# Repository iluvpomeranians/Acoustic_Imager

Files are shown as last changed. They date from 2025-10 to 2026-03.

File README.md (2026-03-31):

# Acoustic Imager – Real-Time Sound Localization

## Overview

This repository contains an **acoustic imaging system** (COEN 490 capstone). A **16-microphone array** localizes sound sources and displays real-time heatmaps, with optional camera overlay, bandpass filtering, and multiple data sources (hardware SPI, simulated, loopback, reference).

https://github.com/user-attachments/assets/3cb0d738-56af-4772-b79c-725c6c1b056e

---

## Key Features

- **16-mic array**: Fermat spiral layout for simulation; measured geometry for hardware (HW/LOOP)
- **Real-time beamforming**: MUSIC and ESPRIT, with 2D MUSIC and covariance smoothing for HW
- **Data sources**: HW (SPI), SIM (simulated), LOOP (SPI loopback), REF (0 dB baseline)
- **Interactive heatmap**: Camera overlay, bandpass filter (draggable range), dB colorbar, colormap options (MAGMA, JET, TURBO, INFERNO)
- **Crosshairs**: Tap heatmap for crosshair with level/trend tooltip; optional 3 s / 12 s tracking
- **Spectrum analyzer**: Frequency bar with cursor; dB / NORM / dBA modes
- **UI**: Frame rate (30 / 60 / MAX), gain (LOW/HIGH), Wi‑Fi modal, settings modal, gallery, video recording, screenshots
- **Position & radar**: Optional compass (magnetometer), GPS, Wi‑Fi geolocation, radar map widget, directional history logging
- **Calibration**: Calibration suite (in-app), camera–array alignment constants, per-mic gain and HW geometry in config

---

## Project Objectives

- Achieve **~9° angular resolution** with a 16-mic array
- Manage spatial aliasing above ~8.6 kHz using **subspace methods** (MUSIC/ESPRIT)
- **Low-level acquisition** on STM32 with SPI transfer to Raspberry Pi
- **Real-time visualization** with interactive controls and multiple sources
- Deliver a **maintainable prototype** with modular software

---

## Team

- **David** – DSP lead, MUSIC/ESPRIT, visualization
- **Basem** – C++ DSP, software architecture
- **Fabian** – Requirements, integration testing
- **Tim** – Literature review, peripheral testing
- **Rob** – Hardware selection, PCB design
- **Ahmad** – Housing, assembly, CAD

---

## Quick Start

Run the application using the deploy script from the repository root:

```bash
sudo ./deploy/deploy_imager.sh
```

First run installs system packages (Python, OpenCV, libcamera, etc.), sets up the systemd service, and starts the UI. On later runs the script only toggles DEV mode or service state unless you request a clean reinstall.

**Clean reinstall** (remove existing service and reinstall):

```bash
sudo ./deploy/deploy_imager.sh --clean
```

Other options: `-status` to show service status, `-dev` to enable/disable DEV mode (skip auto-start for development).

---

## Calibration & Array Geometry

### Array geometry

- **Simulation (SIM)**: Fermat spiral in `config.py` — golden angle ~137.5°, aperture radius 1 cm, `x_coords` / `y_coords` in meters.
- **Hardware (HW / LOOP)**: Measured positions in **payload order** (0=U3 … 15=U14) as `x_coords_hw` and `y_coords_hw` in `config.py`. Generated from `utilities/calibration/array_geometry/`; see `array_geometry.md` for table, CSV, and MUSIC input reference.
- **Pitch**: Mean radial spacing (e.g. `pitch_hw` for HW) is used by the pipeline; geometry scripts output it for reference.

### Camera–array calibration

- In `config.py`: `CALIBRATION_DISTANCE_INCHES` (camera to array center), `CALIBRATION_OFFSET_INCHES` (lateral offset; positive = array right of camera center). Used for overlay alignment and tests. See `utilities/calibration/calibration_test.md` for the test setup.

### Per-mic and pipeline tuning

- **Per-mic gain**: `SPI_MIC_GAIN` in `config.py` (length 16); use `utilities/calibration/metrics_debug.py --live --write-config` to tune.
- **Calibration suite**: In-app via **Settings → Calibration Suite**; can run calibration flow and export results. Standalone app: `utilities/calibration/calibration_standalone_app.py`.

---

## User Interface & Controls

### Mouse

- **Left click**: Buttons, menu items, pills, bandpass handles (drag to set frequency range on the frequency bar).
- **Heatmap**: Tap to show crosshair and level/trend tooltip; tap again near crosshair to dismiss.
- **Spectrum bar**: Double-tap toggles cursor; single tap places or moves the dot.
- **Swipe down** (from top or bottom): Hide top HUD or bottom HUD + menu.
- **Swipe up**: Show HUD/menu. When menu is open, one swipe down closes menu; second swipe hides bottom HUD.
- **Swipe left**: Show menu (horizontal).
- **Single tap** in content (with menu open): Close menu.

### Keyboard

- **Q** or **ESC**: Quit.

### Bottom bar (pills)

- **SHOT**: Screenshot (saved to output folder; gallery refreshes).
- **REC**: Start recording; when recording, same pill toggles **PAUSE**; when paused, **Resume** (yellow) and **Stop** (red) appear.
- **Gallery**: Open gallery (grid of captures/videos; swipe/scroll, select, delete, tags, archive folders).

### Menu (dropdown)

- **Menu** button opens dropdown:
  - **Wi‑Fi**: Scan, connect, disconnect; password screen and on-screen keyboard.
  - **Settings**: Camera on/off, crosshairs, colormap, debug overlay, radar UI, map style (dark/light), position services, record compass history, **Calibration Suite**, email settings, flash firmware. Scrollable panel.
  - **30FPS / MAX**: Frame rate limit (30 or MAX; 60 removed in current UI).
  - **GAIN**: Toggle LOW / HIGH (drives hardware when gain control enabled).
  - **SRC**: Cycle source — HW → SIM → LOOP → REF.
  - **SPECTRUM**: Cycle spectrum mode — dB → NORM → dBA.

### Other UI

- **Top HUD**: Time, battery, FPS, network (e.g. SPI rate); tap pills to expand details.
- **Debug overlay**: Frame count, FPS, source stats, throughput (when debug enabled in settings).
- **Radar widget**: Optional mini map with heading and detections (when radar UI and position services enabled).

---

## Performance

- **FPS modes**: 30, 60 (if re-enabled), or MAX (no cap). Throttling applied each frame when not MAX.
- **Typical (Raspberry Pi 4)**: SIM can reach 60 FPS; HW/LOOP depends on SPI rate and MUSIC/heatmap cost (often 30–60 FPS). Camera overlay and 2D MUSIC reduce FPS.
- **Profiler**: Every 60 frames the main loop prints average stage timings (e.g. `read_source`, `heat_music`, `heat_draw`, `background`, `blend`, `bars`, `ui`, `imshow`, `waitKey`, `total` in ms). Use to find bottlenecks.
- **Tips**: Use 30 FPS when full rate isn’t needed; disable camera or radar if not used; tune `SPI_MUSIC_EVERY_N_FRAMES` and 2D coarse/fine resolution in `config.py` to trade smoothness for speed.

---

**Last updated**: March 2026

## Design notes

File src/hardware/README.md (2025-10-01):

# Hardware

This folder contains all schematics, PCB designs, and CAD files for the device.

---

### Component Testing
- **HF-02-01: Microphone IC Testing**  
  Verify MEMS mic sensitivity and noise floor.  

- **HF-02-02: STM32H7 Testing**  
  Confirm development board boots, runs firmware, and handles acquisition.  

- **HF-02-03: LCD Touchscreen Testing**  
  Ensure the 7-inch display responds to touch and renders frames correctly.  

---

### Power
- **HF-03-01: Battery Pack Assembly**  
  Assemble 18650 battery pack with BMS.  

- **HF-03-02: Power Management**  
  Add regulation circuits for stable 5V/3.3V rails.  

- **HF-03-03/04: Electrical Budget Estimation**  
  Estimate current draw for STM32 and Raspberry Pi subsystems.  

- **HF-03-05: Power Testing**  
  Verify ≥2 hrs runtime and measure voltage sag.  

---

### Mechanical Housing
- **HF-04-01: CAD Design**  
  Design enclosure for mic array, Pi, STM32, battery, and display.  

---

### PCB Design & Testing
- **HF-05-01: Microphone Array Schematic**  
  Draft schematic for mic array connections and decoupling.  

- **HF-05-03/04: Embedded/Power Schematic & Layout**  
  Draw schematic and PCB for STM32, regulators, and connectors.

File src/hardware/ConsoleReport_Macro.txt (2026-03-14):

# ImagerTracker.FCMacro
# Finite, readable “tracker” for Report View: placements + BBoxes + volume/area + Body feature lists
# Also prints a small DELTA vs last run (so you see what changed) without spamming.

import FreeCAD as App
import math, time, json

doc = App.ActiveDocument
if not doc:
    raise RuntimeError("No ActiveDocument. Open your .FCStd first.")

# =======================
# SETTINGS (edit these)
# =======================
MODE = "INCLUDE"          # "INCLUDE" or "SELECTION"
INCLUDE = [
    "Front","Back","Pi5","PowerBoard","Audio_Simpler_PCB","Auidio_Simpler_PCB",
    "rpi_camera_g_detailed","rpi_camera_g_detailed_body_only001","rpi_camera_g_detailed_body_only",
    "rpi_camera_g_detailed_body_only001","rpi_camera_g_detailed_body_only001",
    "LCD","Fan40","BatteryPack_Envelope","BatteryCells_2S2P",
    # common “reference container” names you might be using:
    "References",
]
REF_NAME = ""             # optional: e.g. "Front" ("" disables relative output)

SHOW_SHAPE_STATS = True   # volume/area if available
SHOW_BODY_TREE  = True    # list PartDesign features in each body
MAX_OBJECTS = 80
MAX_FEATURES_PER_BODY = 60
MAX_SKETCH_INFO = 20      # print sketch info for up to N sketches total
PRINT_SKETCH_SUMMARY = True

BB_LIMIT = 1e6

# =======================
# Helpers
# =======================
def bb_is_insane(bb, limit=BB_LIMIT):
    m = max(abs(bb.XMin), abs(bb.XMax), abs(bb.YMin), abs(bb.YMax), abs(bb.ZMin), abs(bb.ZMax))
    return m > limit

def get_obj(key):
    o = doc.getObject(key)
    if o: return o
    try:
        hits = doc.getObjectsByLabel(key)
        if hits: return hits[0]
    except:
        pass
    return None

def safe_shape(o):
    try:
        sh = o.Shape
        if sh.isNull():
            return None
        bb = sh.BoundBox
        if bb_is_insane(bb):
            return None
        return sh
    except:
        return None

def placement_of(o):
    try:
        if hasattr(o, "getGlobalPlacement"):
            return o.getGlobalPlacement()
    except:
        pass
    return o.Placement

def rot_pack(r):
    ax = r.Axis
    ang = math.degrees(r.Angle)
    try:
        q = tuple(r.Q)  # (x,y,z,w)
    except:
        q = None
    return ax, ang, q

def rel_placement(pl_ref, pl_obj):
    try:
        return pl_ref.inverse().multiply(pl_obj)
    except:
        rp = App.Placement()
        rp.Base = pl_obj.Base.sub(pl_ref.Base)
        rp.Rotation = pl_obj.Rotation
        return rp

def fmt_vec(v):
    return f"({v.x:.3f}, {v.y:.3f}, {v.z:.3f})"

def fmt_bb(bb):
    return f"X[{bb.XMin:.2f},{bb.XMax:.2f}] Y[{bb.YMin:.2f},{bb.YMax:.2f}] Z[{bb.ZMin:.2f},{bb.ZMax:.2f}]"

def fmt_size(bb):
    return f"W={bb.XLength:.2f}  T={bb.YLength:.2f}  H={bb.ZLength:.2f}"

# =======================
# Delta store (so you can see changes run-to-run)
# =======================
PARAM_PATH = "User parameter:BaseApp/Preferences/Macros/ImagerTracker"
pg = App.ParamGet(PARAM_PATH)

def load_prev():
    try:
        s = pg.GetString("prev_state", "")
        if not s:
            return {}
        return json.loads(s)
    except:
        return {}

def save_prev(state):
    try:
        pg.SetString("prev_state", json.dumps(state))
    except:
        pass

prev_state = load_prev()
cur_state = {}

# =======================
# Select targets
# =======================
targets = []

if MODE.upper() == "SELECTION":
    # If you want selection mode, select objects in tree, then run macro
    sel = App.Gui.Selection.getSelection() if App.GuiUp else []
    targets = sel[:MAX_OBJECTS]
else:
    # INCLUDE mode: match by Name OR Label
    for o in doc.Objects:
        if len(targets) >= MAX_OBJECTS:
            break
        if INCLUDE:
            if (o.Name not in INCLUDE) and ((getattr(o, "Label", "") or "") not in INCLUDE):
                continue
        targets.append(o)

# reference object (optional)
ref = get_obj(REF_NAME) if REF_NAME else None
ref_pl = placement_of(ref) if ref else None

# =======================
# Print header
# =======================
print("\n=== ImagerTracker (finite) ===")
print("Time:", time.strftime("%Y-%m-%d %H:%M:%S"))
print("Doc :", doc.Name)
try:
    print("File:", doc.FileName)
except:
    pass

if MODE.upper() == "SELECTION":
    print("Mode: SELECTION")
else:
    print("Mode: INCLUDE  (edit INCLUDE list at top)")

if ref:
    print(f"Reference: {ref.Name} ({ref.Label})")
else:
    print("Reference: (none)")

finite_bbs = []
sketch_printed = 0

# =======================
# Object listing
# =======================
for o in targets:
    sh = safe_shape(o)
    if not sh:
        continue

    pl = placement_of(o)
    base = pl.Base
    ax, ang, q = rot_pack(pl.Rotation)
    bb = sh.BoundBox

    # store state for delta
    cur_state[o.Name] = {
        "base": [base.x, base.y, base.z],
        "axis": [ax.x, ax.y, ax.z],
        "ang": ang,
        "bb": [bb.XMin, bb.XMax, bb.YMin, bb.YMax, bb.ZMin, bb.ZMax],
    }

    print(f"\n- {o.Name} | {o.Label} | {o.TypeId}")
    print(f"  Base: {fmt_vec(base)}")
    print(f"  Rot : Axis=({ax.x:.3f},{ax.y:.3f},{ax.z:.3f})  Angle(deg)={ang:.3f}")
    if q:
        print(f"  Q   : ({q[0]:.6f}, {q[1]:.6f}, {q[2]:.6f}, {q[3]:.6f})")

    print(f"  BBox: {fmt_bb(bb)}")
    print(f"  Size: {fmt_size(bb)}")

    if SHOW_SHAPE_STATS:
        try:
            # Part::Feature / PartDesign features usually have these
            print(f"  Volume: {sh.Volume:.2f} mm^3")
            print(f"  Area  : {sh.Area:.2f} mm^2")
        except:
            pass

    if ref_pl:
        rpl = rel_placement(ref_pl, pl)
        rb = rpl.Base
        rax, rang, rq = rot_pack(rpl.Rotation)
        print(f"  Rel-> {REF_NAME} Base: {fmt_vec(rb)}")
        print(f"  Rel-> {REF_NAME} Rot : Axis=({rax.x:.3f},{rax.y:.3f},{rax.z:.3f})  Angle(deg)={rang:.3f}")

    finite_bbs.append(bb)

    # sketch summary (bounded)
    if PRINT_SKETCH_SUMMARY and sketch_printed < MAX_SKETCH_INFO and o.TypeId.startswith("Sketcher::SketchObject"):
        try:
            dof = getattr(o, "DegreeOfFreedom", None)
            gc  = len(getattr(o, "Geometry", []))
            cc  = len(getattr(o, "Constraints", []))
            fc  = getattr(o, "FullyConstrained", None)
            print(f"  Sketch: geom={gc}  constraints={cc}  dof={dof}  fully={fc}")
            sketch_printed += 1
        except:
            pass

# =======================
# Body feature trees (bounded)
# =======================
if SHOW_BODY_TREE:
    for b in doc.Objects:
        if b.TypeId != "PartDesign::Body":
            continue

        if MODE.upper() != "SELECTION" and INCLUDE:
            if (b.Name not in INCLUDE) and ((getattr(b, "Label", "") or "") not in INCLUDE):
                continue

        print(f"\n=== BODY: {b.Name} ({b.Label}) ===")
        try:
            tip = getattr(b, "Tip", None)
            if tip:
                print(f"  Tip: {tip.Name} ({tip.Label})")
        except:
            pass

        try:
            feats = list(b.Group)
        except:
            feats = []

        shown = 0
        for f in feats:
            if shown >= MAX_FEATURES_PER_BODY:
                print(f"  ... (truncated after {MAX_FEATURES_PER_BODY} features)")
                break
            if "Origin" in f.Name or f.TypeId.startswith("App::Origin"):
                continue
            print(f"  - {f.Name:24s} | {getattr(f,'Label','')} | {f.TypeId}")
            shown += 1

# =======================
# Overall envelope
# =======================
if finite_bbs:
    bb_all = finite_bbs[0]
    for b in finite_bbs[1:]:
        bb_all.add(b)
    print("\n=== OVERALL ENVELOPE (finite only) ===")
    print(f"Size: {fmt_size(bb_all)}  (mm)")
    print(f"BB  : {fmt_bb(bb_all)}")

# =======================
# Delta vs last run
# =======================
def delta_line(name, p0, p1, label):
    d = [p1[i]-p0[i] for i in range(len(p0))]
    if any(abs(x) > 1e-6 for x in d):
        print(f"  {name:28s} {label}: Δ({', '.join(f'{x:.3f}' for x in d)})")

print("\n=== DELTA vs previous run (if any) ===")
if not prev_state:
    print("  (no previous state saved yet)")
else:
    for name, st in cur_state.items():
        if name not in prev_state:
            print(f"  {name}: NEW")
            continue
        old = prev_state[name]
        delta_line(name, old.get("base",[0,0,0]), st.get("base",[0,0,0]), "Base")

        obb = old.get("bb",[0,0,0,0,0,0])
        nbb = st.get("bb",[0,0,0,0,0,0])
        o_len = [obb[1]-obb[0], obb[3]-obb[2], obb[5]-obb[4]]
        n_len = [nbb[1]-nbb[0], nbb[3]-nbb[2], nbb[5]-nbb[4]]
        delta_line(name, o_len, n_len, "BBoxSize")

        if abs(old.get("ang",0)-st.get("ang",0)) > 1e-6:
            print(f"  {name:28s} RotAngle: {old.get('ang',0):.3f} -> {st.get('ang',0):.3f}")

save_prev(cur_state)

print("\n=== End ImagerTracker ===\n")

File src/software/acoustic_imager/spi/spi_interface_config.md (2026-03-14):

# Acoustic Imager config reference

See [config.py](config.py) for the live configuration. This doc summarizes the two SPI interface modes and their pinouts.

## SPI interface modes

Set `SPI_INTERFACE` in config.py to `0` or `1` to choose the Pi SPI bus and chip-select. **J2** is the STM32-side header (lines 1–10) per the ribbon cable pinout.

| Item | SPI INTERFACE 0 | SPI INTERFACE 1 |
| --- | --- | --- |
| **config.py** | `SPI_INTERFACE = 0` | `SPI_INTERFACE = 1` |
| **Device** | `/dev/spidev0.0` | `/dev/spidev1.2` |
| **SPI_BUS / SPI_DEV** | 0, 0 | 1, 2 |

---

| Purpose | STM-32 PINOUT (J2) | RASPI PINOUTS (SPI0) | RASPI PINOUTS (SPI1) |
| --- | --- | --- | --- |
| Gain control (AUTO_GAIN_CNTL) | 1 | 22 | 22 |
| Frame-ready (MCU_STATUS) | 2 | 26 | 26 |
| RPI status | 3 | 27 | 27 |
| GND | 4 | 20 | 25 |
| SCLK | 5 | 23 | 40 |
| Chip select (NSS) | 6 | 24 | 36 |
| MISO | 7 | 21 | 35 |
| MOSI | 8 | 19 | 38 |
| GND | 9 | 25 | 39 |
| NRST | 10 | 28 | 28 |

## Sanity check: switching `SPI_INTERFACE` (e.g. to 0)

When you set `SPI_INTERFACE = 0` or `1` in config.py, **all** of the following are taken from the same table; there is no separate Pi config file for SPI:

| config.py | SPI0 (interface 0) | SPI1 (interface 1) |
|---|---|---|
| `_SPI_PIN_SETUPS[n]` | (0, 0, 7, 25) | (1, 2, 7, 25) |
| → Device | /dev/spidev0.0 | /dev/spidev1.2 |
| → Frame-ready (BCM) | 7 (physical 26) | 7 (physical 26) |
| → Gain ctrl (BCM) | 25 (physical 22) | 25 (physical 22) |

- **SPIManager** (HW source) reads only `config.SPI_BUS`, `config.SPI_DEV`, `config.FRAME_READY_BCM_PIN`, `config.GAIN_CTRL_BCM_PIN` — all derived from `_SPI_PIN_SETUPS[SPI_INTERFACE]`. No environment variables.
- **deploy_imager.sh** does not set `ACOUSTIC_SPI_BUS` / `ACOUSTIC_SPI_DEV`; the app uses config.py only.
- Other deploy scripts (e.g. deploy_imager_acousticgod.sh) may set `ACOUSTIC_SPI_BUS=1 ACOUSTIC_SPI_DEV=0` in the process; those env vars affect only **LOOP** mode (spi_loopback_source), not **HW** mode (spi_manager). If you use the main deploy_imager.sh, ignore them.

So for "SPI open failed": ensure (1) the chosen device exists (`ls /dev/spidev*`), (2) `dtparam=spi=on` or SPI1 overlay is set, (3) user is in group `spi`, and (4) config.py has the intended `SPI_INTERFACE` and no typo in `_SPI_PIN_SETUPS`.

Notes:

- **SPI0** uses the Pi's main 40-pin header (pins 19, 21, 23, 24).
- **SPI1** is the auxiliary SPI; enable with `dtoverlay=spi1-3cs` in `/boot/config.txt`. CE2 gives `/dev/spidev1.2`.
- Frame-ready (MCU_STATUS) is an input to the Pi (STM32 drives it). Gain control (AUTO_GAIN_CNTL) is an output from the Pi (drives STM32).

## Enabling SPI (fix "no such file" / device missing)

If you see **SPI open failed … No such file or directory**:

**Diagnostic first:** From the repo root run:
```bash
bash utilities/calibration/check_spi_devices.sh
```
This prints which boot config is used, whether SPI is enabled there, and whether `/dev/spidev*` exists.

**Boot config location:** On Raspberry Pi OS Bookworm/Trixie and Pi 5, the active config is often `/boot/firmware/config.txt` (not `/boot/config.txt`). Check both; the one that exists and is modified by raspi-config is the one that counts.

1. **SPI0** (`/dev/spidev0.0`): Enable the main SPI interface:
   - `sudo raspi-config` → **Interface Options** → **SPI** → Enable → Finish.
   - **Or manually:** In the active config file (see above), ensure this line is present and **not** commented: `dtparam=spi=on`
   - Reboot. Then check: `ls -l /dev/spidev*` (you should see `/dev/spidev0.0`).

2. **SPI1** (`/dev/spidev1.2`): Enable the auxiliary SPI and reboot:
   - In the active config (e.g. `/boot/firmware/config.txt` or `/boot/config.txt`), add: `dtoverlay=spi1-3cs`
   - Reboot. Then check: `ls -l /dev/spidev*` (you should see `spidev1.0`, `spidev1.1`, `spidev1.2`).

3. Ensure your user can access the device: `sudo usermod -a -G spi $USER` (log out and back in, or reboot).

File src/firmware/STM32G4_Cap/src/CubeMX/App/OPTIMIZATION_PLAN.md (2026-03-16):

# App Layer Cycle-Reduction Plan

## Context

- **Target:** This `App` folder (STM32G4 Acoustic Imager firmware).
- **Goal:** Reduce clock cycles per frame. Typical budget is ~1.8M CC/frame with ~1M CC consumed by FFT; the rest is checksum, battery read, clipping scan, ADC/DC steps, and payload assembly.
- **Config:** All options are compile-time in [app_main.h](app_main.h).

---

## Optimizations Implemented

| # | Optimization | Config switch | Location | Effect | Host / protocol impact |
|---|---|---|---|---|---|
| 1 | **Checksum off** | `SPI_CHECKSUM_ENABLE` (0 = off) | [transport/spi_stream.c](transport/spi_stream.c): `spi_stream_build_frame_header`, `spi_stream_finalize_frame` | ~300k CC/frame saved when off | Host must treat frame length as **header + payload only** (no trailing 2 bytes). |
| 2 | **Battery every N frames** | `APP_BATTERY_READ_EVERY_N_FRAMES` (e.g. 8) | [app_main.c](app_main.c): `app_process_synced_window`; cache in `battery_millivolts_cached`; CLI uses `app_get_cached_battery_mv()` | ~100k CC per frame saved when N > 1 (read every Nth frame) | Battery in header/status updates at most every N frames. |
| 3 | **Clipping scan off** | `APP_CLIP_DETECT_ENABLE` (0 = off) | [app_main.c](app_main.c): `app_process_synced_window` | Saves full clipping scan over all ADCs × FRAME_SIZE × channels | `SPI_FRAME_FLAG_TIME_CLIPPING` never set; clip counters stay 0. |
| 4 | **ADC + DC in one step** | (no switch) | [dsp/dsp_pipeline.c](dsp/dsp_pipeline.c): `process_adc_to_float_and_remove_dc`, used by `process_adc_channel_pipeline` | One fewer full pass over the buffer per channel (merge de-interleave + DC sum + DC remove into two loops) | None. |
| 5 | **Bulk payload copy** | `SPI_FRAME_PAYLOAD_BYTES` (spi_stream.h) | [app_main.c](app_main.c): after the 16× FFT+avg loop, one memcpy of SPI_FRAME_PAYLOAD_BYTES from &fft_avg[0][0]; no runtime size check | Single bulk copy; no per-frame capacity check | None. |
| 6 | **Optional: no FFT repack** | Not implemented | [dsp/dsp_pipeline.c](dsp/dsp_pipeline.c): `apply_fft` → `pack_rfft_complex_bins` | Saves repack step if host accepts CMSIS packed layout | Host must accept **CMSIS packed** FFT output (512 floats) instead of current complex layout. |

---

## Config Summary (app_main.h)

```c
#define SPI_CHECKSUM_ENABLE       0   /* 0 = no checksum; host uses header+payload only */
#define APP_BATTERY_READ_EVERY_N_FRAMES 8u   /* Read battery every N frames */
#define APP_CLIP_DETECT_ENABLE    0   /* 0 = skip clipping scan */
```

---

## Testing Order

1. **CRC off** – Build with `SPI_CHECKSUM_ENABLE 0`, run host with frame length = header + payload (no checksum bytes). Measure CC/frame.
2. **Battery cache** – Set `APP_BATTERY_READ_EVERY_N_FRAMES` to 8 or 16; confirm status/battery CLI still report and that header battery updates every N frames.
3. **Clipping off** – Set `APP_CLIP_DETECT_ENABLE` to 0; confirm no clip flags and that clip counters remain 0.
4. **ADC+DC merge** – No config change; confirm FFT/SPI output unchanged (e.g. compare with previous build).
5. **Bulk copy** – No config change; confirm frame content and length unchanged.

---

## Optional: Remove FFT Repacking (Item 6)

- **Condition:** Host must accept CMSIS real-FFT packed format (same 512 floats, different layout).
- **Change:** In `apply_fft`, call `arm_rfft_fast_f32(..., input, fft_output, 0)` and do **not** call `pack_rfft_complex_bins`. Use `fft_output` (packed) for `update_fft_bin_average` and for SPI payload.
- **Caveat:** Any code that expects the current complex layout (e.g. `calculate_magnitude`) must be updated to use packed format or keep a separate unpacked buffer for that path.

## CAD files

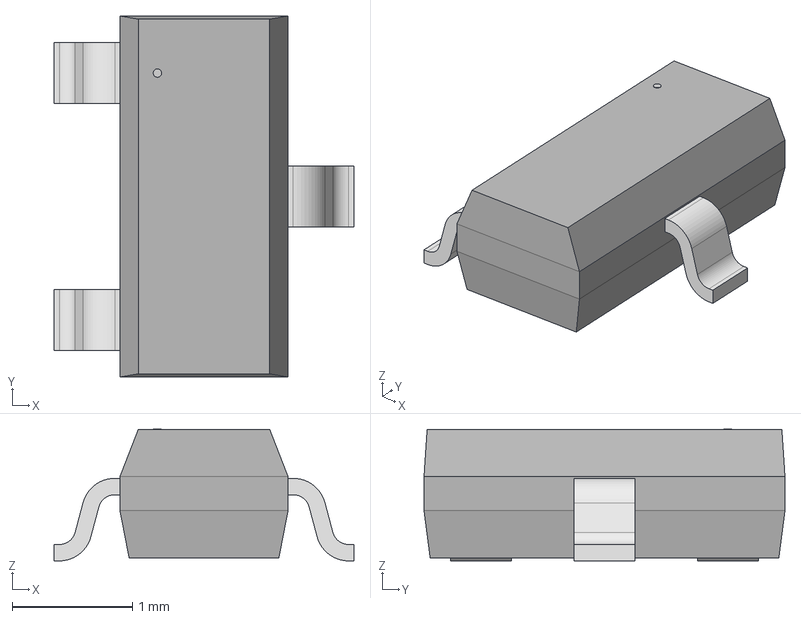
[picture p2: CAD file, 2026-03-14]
src/hardware/component_step_files/low_level_components/DMN3731U-7_DIO.step
2.49 x 3.00 x 1.09 mm

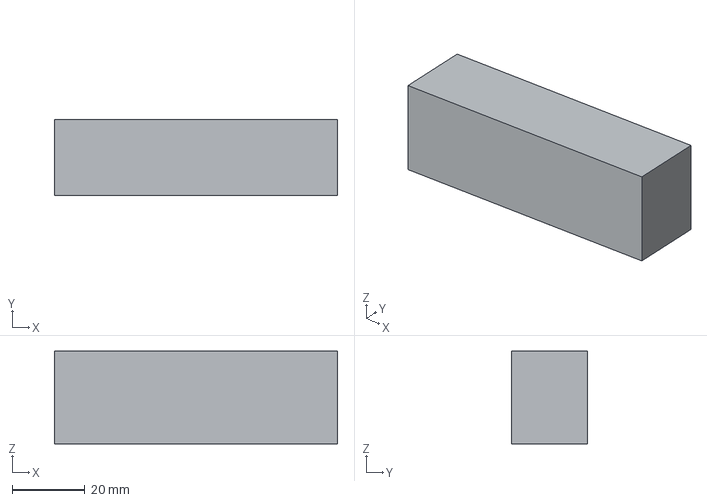
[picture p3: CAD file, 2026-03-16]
src/hardware/component_step_files/One_Battery_Slot.step
78.0 x 21.0 x 25.5 mm

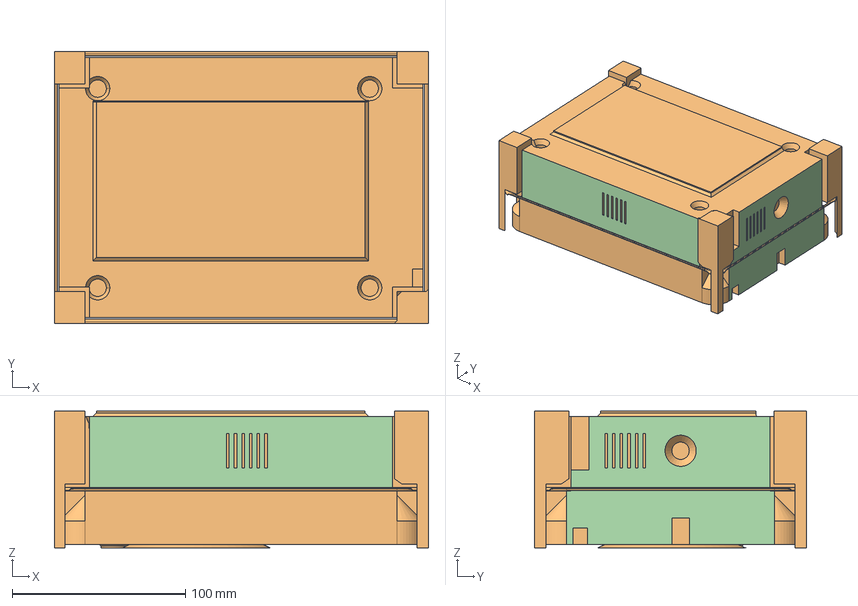
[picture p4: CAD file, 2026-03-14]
src/hardware/for_airflow/Inverse_body_cut_for_airflow.FCStd
216.0 x 157.0 x 79.0 mm
FINAL_BODY_FOR_AIRFLOW
wall
inlet
open

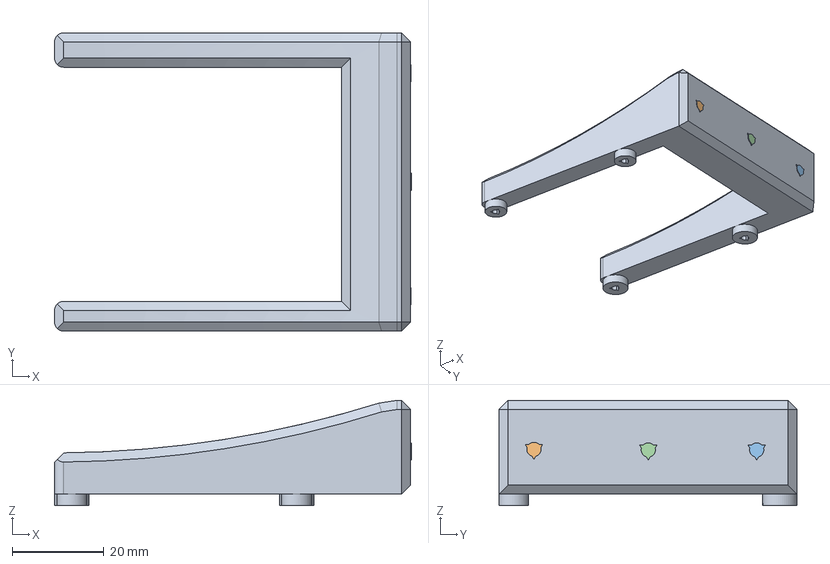
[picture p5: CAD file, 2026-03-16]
src/hardware/Pi_Base/Pi_Base_Support.FCStd
77.8 x 65.0 x 22.9 mm
before_side_screws
M3_Screw_pi001
M3_Screw_pi002
M3_Screw_pi003

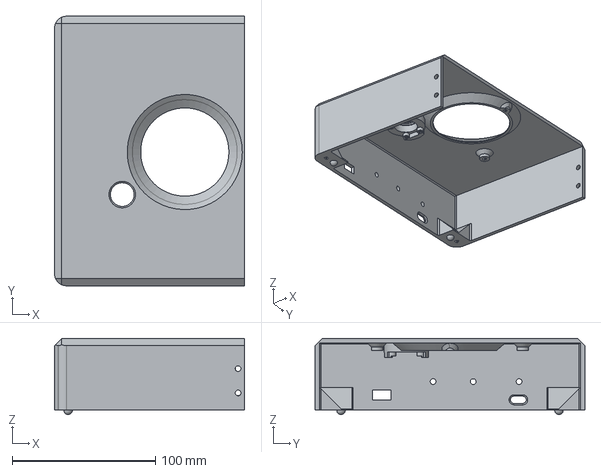
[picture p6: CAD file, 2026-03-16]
src/hardware/result_step_files/bottom/Quarters-Cut_BL_CounterSink.step
132.5 x 188.0 x 53.0 mm

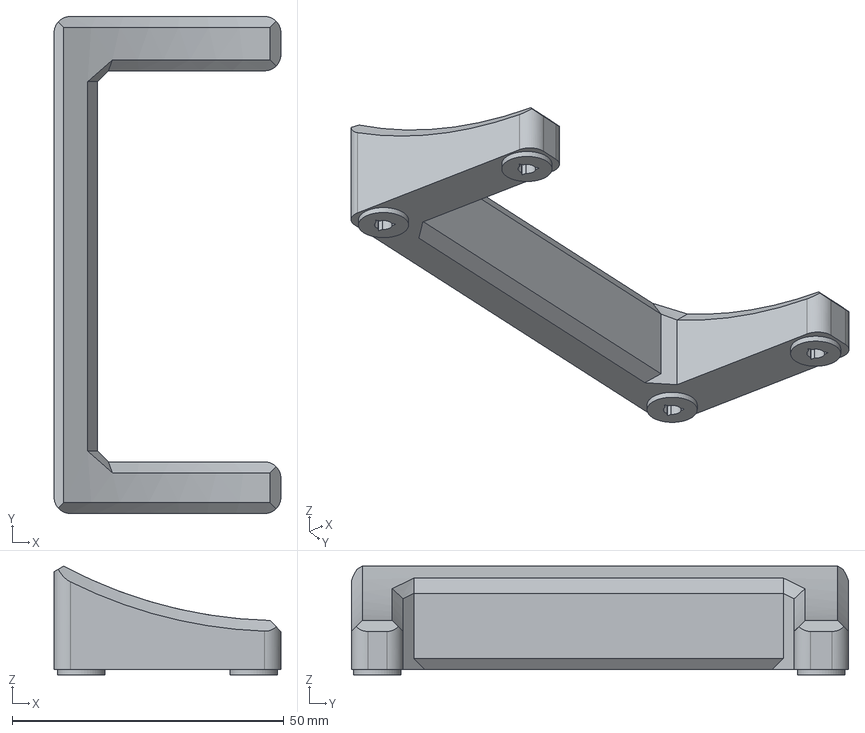
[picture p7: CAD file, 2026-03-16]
src/hardware/result_step_files/power_base/PowerBoard_Support_Stand-Cut.step
41.8 x 91.5 x 20.0 mm

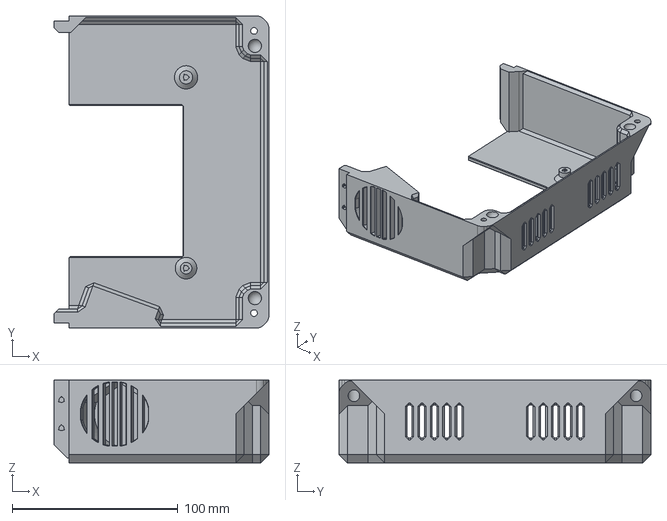
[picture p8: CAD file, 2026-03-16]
src/hardware/result_step_files/top/Quarters-Cut_TR_fan.step
129.5 x 188.0 x 50.0 mm

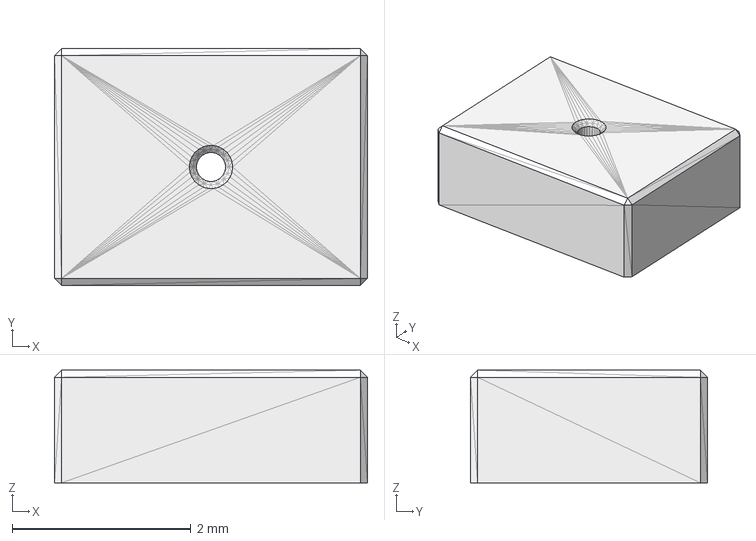
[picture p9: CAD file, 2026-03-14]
src/hardware/component_step_files/low_level_components/SPH8878LR5H_1_Accurate.step
3.50 x 2.65 x 1.26 mm

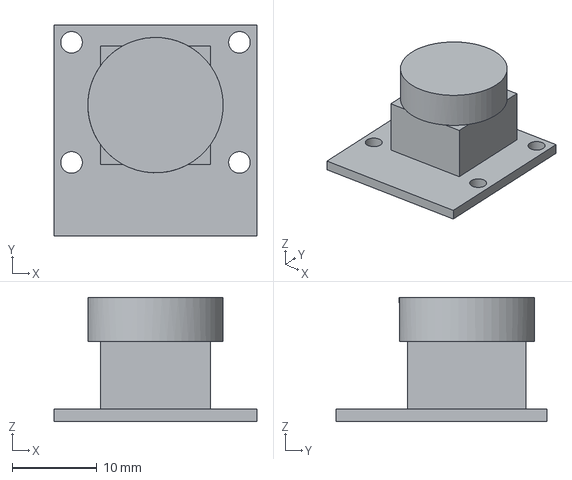
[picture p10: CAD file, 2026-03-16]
src/hardware/component_step_files/My_CAM.step
24.0 x 25.0 x 14.7 mm

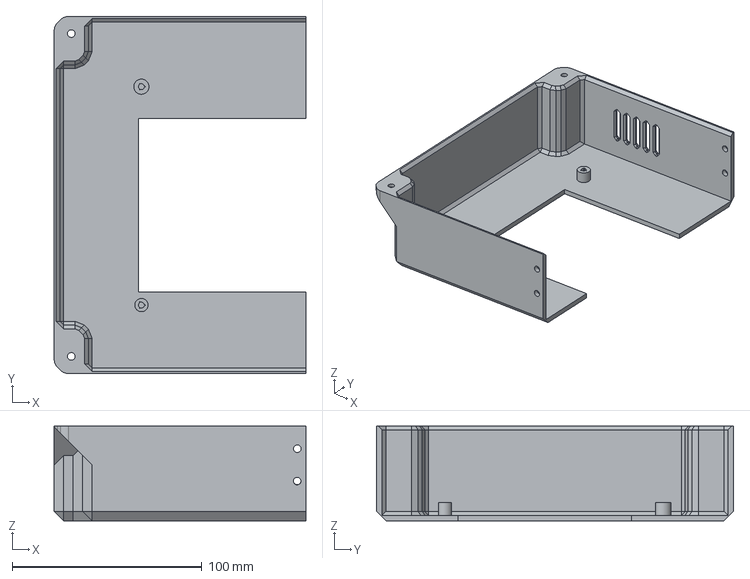
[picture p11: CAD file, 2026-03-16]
src/hardware/result_step_files/top/Quarters-Cut_TL.step
132.5 x 188.0 x 50.0 mm

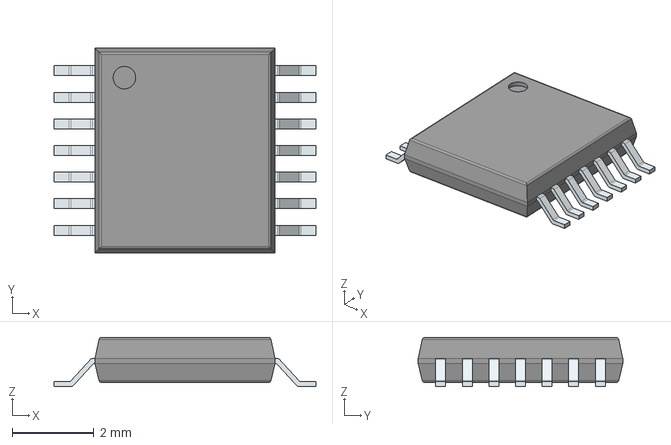
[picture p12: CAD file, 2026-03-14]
src/hardware/component_step_files/low_level_components/TPH2504-TR.stp
6.40 x 5.00 x 1.20 mm
PinsArrayLR

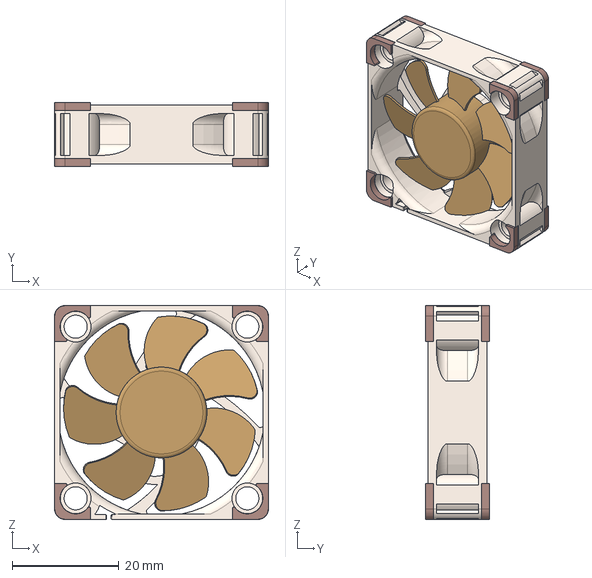
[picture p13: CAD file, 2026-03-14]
src/hardware/component_step_files/Noctua-Fan-NF-A4x10_40mm.stp
40.1 x 12.0 x 40.1 mm
Noctua-NF-A4x10 v1
Noctua nf-a8-pwm fan 80x80x25 v2

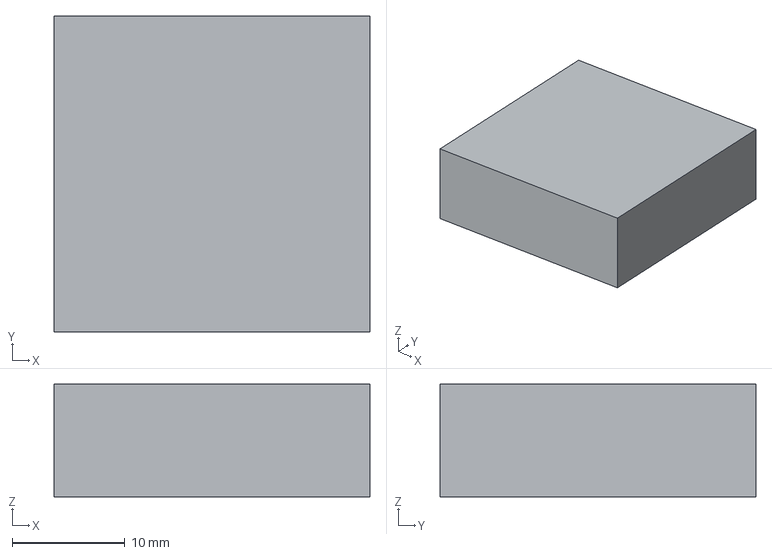
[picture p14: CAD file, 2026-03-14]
src/hardware/component_step_files/GPS_Box.step
28.0 x 28.0 x 10.0 mm

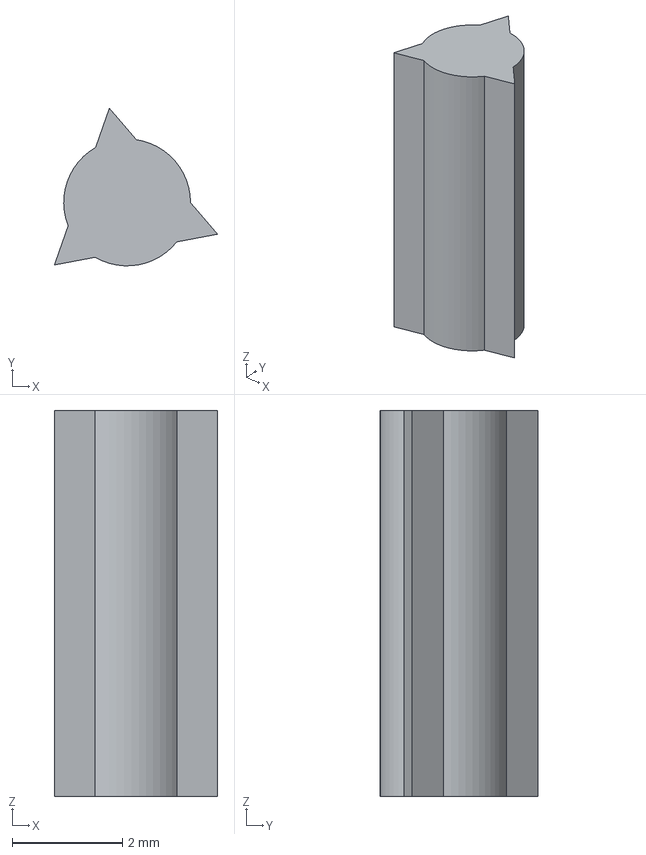
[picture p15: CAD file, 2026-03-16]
src/hardware/component_step_files/CAM_screws.step
2.96 x 2.86 x 7.00 mm

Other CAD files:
src/hardware/result_step_files/pi/Pi_Base_Support-Cut.step
src/hardware/result_step_files/bottom/Quarters-Cut_BR.step
src/hardware/component_step_files/M4_Fan_screw_8mm.step
src/hardware/component_step_files/M3.5x8mm Screw Hole Positive-Body.step
src/hardware/result_step_files/bottom/Quarters-Cut_BL_CounterSink.stl
src/hardware/result_step_files/bottom/Quarters-Cut_BR.stl
src/hardware/result_step_files/pi/Pi_Base_Support-Cut.stl
src/hardware/result_step_files/power_base/PowerBoard_Support_Stand-Cut.stl
src/hardware/result_step_files/top/Quarters-Cut_TL.stl
src/hardware/result_step_files/top/Quarters-Cut_TR_fan.stl

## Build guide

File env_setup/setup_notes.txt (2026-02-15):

===========================================================
 Acoustic Imager – Raspberry Pi Setup Instructions / Notes
===========================================================
This document assumes:
– Raspberry Pi OS (64-bit) has been flashed to a microSD
– You have a monitor or the Pi touchscreen attached
– You will be cloning this repo onto the Pi directly

1. Flash Raspberry Pi OS
-------------------------
Use the Raspberry Pi Imager to flash:

    Raspberry Pi OS (64-bit)

Insert the SD card into the Pi and boot normally.

2. Power the Raspberry Pi
--------------------------
Use a proper USB-C power supply:

    • Recommended: 5V / 5A (official supply)
    • Temporary: laptop USB-C charger (5V/3A minimum)

Under-powering the board can cause:
– Camera not detected
– Crashes when running NumPy/SciPy/OpenCV
– Random freezes

3. Install required packages (handling this through script)
-----------------------------
Open Terminal on the Pi:

    sudo apt update
    sudo apt install -y python3 python3-pip python3-numpy python3-scipy python3-opencv python3-venv python3-dev git
    sudo apt install -y libcamera0 libcamera-apps libcamera-tools python3-libcamera python3-kms++

4. Clone the GitHub repository
-------------------------------
Inside the Pi terminal:

    git clone https://github.com/YOUR_TEAM/AcousticImager.git
    cd AcousticImager

5. (Recommended) Create a Python virtual environment
-----------------------------------------------------
    python3 -m venv venv
    source venv/bin/activate

If your repo has a requirements.txt file:

    pip install -r requirements.txt

6. Enable the Raspberry Pi Camera
----------------------------------
    sudo raspi-config

Navigate to:
    Interface Options → Camera → Enable

Test the camera:

    libcamera-hello

7. Run the Python simulations
------------------------------
From inside the repository folder:

    source venv/bin/activate
    python3 your_simulation_script.py

This verifies:
– MUSIC performance
– Heatmap rendering
– UI responsiveness
– OpenCV functionality

8. (Later) Camera + Heatmap Overlay
------------------------------------
When ready, create a Python script that:
– Reads live frames from the Pi camera (OpenCV/libcamera)
– Computes or receives beamforming heatmap
– Uses cv2.addWeighted() to overlay heatmap onto video
– Displays in real time (15–25 FPS goal)

===========================================================
 NOTES FOR FUTURE DEVELOPMENT
===========================================================

1. DearPyGUI (IMPORTANT)
-------------------------
Consider migrating your UI to **DearPyGUI** for the final version.
It is:
– GPU accelerated (much faster on Raspberry Pi 5)
– Cleaner than Tkinter or PyQt
– Very good for heatmaps, sliders, real-time plotting
– Similar to your existing simulator UI workflow

Make a note to evaluate DearPyGUI once the core
MUSIC + camera pipeline is stable.

2. Auto-Startup (Optional)
---------------------------
Later, you can create a systemd service so that your UI
launches automatically when the Pi boots — ideal for
the final handheld device.

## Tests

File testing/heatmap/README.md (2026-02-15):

# Acoustic Imager - Heatmap Pipeline Test

This directory contains the test script for the Acoustic Imager heatmap pipeline, which simulates real-time audio visualization using heatmaps overlaid on video frames.

## Overview

The heatmap pipeline test script demonstrates the core functionality of the Acoustic Imager system:

1. **Fake Data Generation**: Creates realistic heatmap data using NumPy arrays
2. **Heatmap Visualization**: Converts data to colored heatmaps using OpenCV
3. **Frame Overlay**: Blends heatmaps onto background frames with alpha transparency
4. **Real-time Display**: Shows results in an OpenCV window
5. **FFmpeg Recording**: Streams frames to FFmpeg for hardware-accelerated video recording

## Files

- `heatmap_pipeline_test.py` - Main test script implementing the complete pipeline
- `requirements.txt` - Python dependencies
- `README.md` - This documentation file

## Requirements

### Python Dependencies
Install the required Python packages:
```bash
pip install -r requirements.txt
```

### System Dependencies
- **FFmpeg**: Must be installed on your system for video recording
  - Ubuntu/Debian: `sudo apt install ffmpeg`
  - macOS: `brew install ffmpeg`
  - Windows: Download from [ffmpeg.org](https://ffmpeg.org/download.html) or use `winget install ffmpeg`

## Usage

Run the test script:

**On macOS/Linux:**
```bash
python3 heatmap_pipeline_test.py
```

**On Windows:**
```cmd
python heatmap_pipeline_test.py
```

### Controls
- **q**: Quit the simulation early
- **Close window**: Exit the program

### Output
- Real-time display window showing the heatmap overlay
- Video file: `heatmap_output.mp4` (saved in the same directory)

## Configuration

You can modify these parameters in the `main()` function:

- `WIDTH`, `HEIGHT`: Video dimensions (default: 640x480)
- `FPS`: Frames per second (default: 30)
- `NUM_FRAMES`: Number of frames to generate (default: 100)
- `ALPHA`: Heatmap transparency (0.0-1.0, default: 0.7)
- `OUTPUT_FILE`: Output video filename

## Architecture

The script is organized into modular functions:

### Core Functions
- `generate_fake_heatmap()`: Creates random heatmap data with spatial correlation
- `apply_heatmap_overlay()`: Converts data to colored heatmap and blends with background
- `send_to_ffmpeg()`: Streams frames to FFmpeg subprocess
- `setup_ffmpeg_process()`: Initializes FFmpeg with hardware acceleration
- `cleanup_ffmpeg_process()`: Properly closes FFmpeg subprocess

### FFmpeg Configuration
The script automatically selects the appropriate encoder based on your platform:

**macOS**: Uses `h264_videotoolbox` (hardware-accelerated)
**Linux/Raspberry Pi**: Uses `h264_v4l2m2m` (hardware-accelerated)  
**Windows**: Uses `libx264` (software encoder)

Example FFmpeg command structure:
```bash
ffmpeg -y -f rawvideo -pix_fmt bgr24 -s 640x480 -r 30 -i - \
  -c:v h264_v4l2m2m -b:v 2M output.mp4
```

This configuration:
- Uses `h264_v4l2m2m` encoder for Raspberry Pi hardware acceleration
- Accepts raw BGR24 video input from stdin
- Records at 2Mbps bitrate
- Outputs to MP4 format

## Integration Notes

This test script simulates the heatmap pipeline that will be integrated into the full Acoustic Imager system. In the actual implementation:

1. **Audio Processing**: Replace `generate_fake_heatmap()` with real audio analysis
2. **Real-time Performance**: Optimize for actual audio processing latency
3. **Hardware Integration**: Adapt FFmpeg settings for specific hardware platforms
4. **Error Handling**: Add robust error handling for production use

## Troubleshooting

### Common Issues
1. **FFmpeg not found**: Ensure FFmpeg is installed and in your system PATH
2. **Hardware encoder not available**: The `h264_v4l2m2m` encoder is specific to Raspberry Pi. On other systems, use `libx264` instead
3. **Permission errors**: Ensure write permissions for the output directory

### Performance Notes
- The script includes frame rate control to maintain consistent timing
- FFmpeg subprocess is properly managed with cleanup on exit
- Memory usage is optimized by processing frames one at a time

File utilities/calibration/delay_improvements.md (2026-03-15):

# Delay / Latency Improvements Reference

Reference for the acoustic imager pipeline timing and where to optimize next. Check this before starting latency work.

## Pipeline stages (ms by revision)

| Stage | rev0 (ms) | rev1 (ms) | rev2 (ms) | Notes |
|---|---|---|---|---|
| read | 0.05 | 0.06 | 0.06 | |
| heat_music | 16–19 | ~6.1 | ~4.8 | MUSIC / DSP; rev1 after coarser grid + every-2nd-frame + two-stage |
| heat_stability| 0.01 | 0.01 | 0.01 | |
| heat_draw | 11–12 | ~13.9 | ~12.3 | Heatmap drawing |
| heat_scale | 11–20 | ~17.7 | ~15.5 | Scaling; rev2 histogram percentile (stretch kept) |
| heat | 10–13 | ~11.9 | ~11.5 | Heatmap pipeline (pre-draw) |
| bg | 2.7–3 | ~1.9 | ~1.2 | Background |
| blend | 13–15 | ~11.9 | ~9.5 | Heatmap blend (already optimized) |
| bars | 12–13 | ~15.6 | ~12.0 | DB + freq bar drawing |
| ui | 8–9 | ~8.5 | ~12.5 | Rest of UI drawing |
| imshow | <1 | ~1.3 | ~1.5 | Display |
| waitKey | 11–13 | ~10.4 | ~9.5 | UI event loop (often fixed) |

**Total** rev0 ~106–114 ms → rev1 ~99–103 ms → rev2 ~92–93 ms.

- **rev0**: Baseline (before heat_music optimizations).
- **rev1**: After ANGLES_2D_RESOLUTION=35, SPI_MUSIC_EVERY_N_FRAMES=2, two-stage 2D MUSIC (coarse 21 + 5×5 refine).
- **rev2**: After histogram-based percentile for contrast stretch (blobs visible); total ~92–93 ms.

## Priority order for optimization (rev2)

1. **heat_scale** (~15.5 ms) — Subsample percentile or every-N-frames if more gain needed.
2. **heat_draw** (~12.3 ms) — Heatmap drawing; lower res or simpler path.
3. **bars** (~12 ms) — DB + freq bar; reuse or simplify.
4. **ui** (~12.5 ms) — Rest of UI; fewer redraws or cache static elements.
5. **heat** (~11.5 ms) — Upstream of heat_draw.

`waitKey` is often a fixed 10–15 ms and may be hard to reduce.

## Already done

- **Blend**: Fused colormap+weight LUT (no applyColorMap + first multiply); optional half-res blend (`config.BLEND_HALF_RES`). LUT writes use contiguous single-channel buffers to satisfy OpenCV `cv2.LUT` dst layout.
- **heat_music**: (1) `ANGLES_2D_RESOLUTION` reduced to 35 (from 51) for coarser 2D grid; (2) `SPI_MUSIC_EVERY_N_FRAMES = 2` to run 2D MUSIC every other frame and reuse cached angles/spec; (3) two-stage 2D MUSIC when `SPI_MUSIC_2D_COARSE_RESOLUTION > 0` (e.g. 21): coarse grid then small fine patch around peak via `music_spectrum_2d_refined` in `dsp/beamforming.py`, with `SPI_MUSIC_2D_REFINE_HALF_WIDTH` (e.g. 2 → 5×5 patch). Set `SPI_MUSIC_2D_COARSE_RESOLUTION = 0` to disable two-stage and use full grid only.
- **heat_scale**: Contrast stretch uses `percentile_uint8_fast` (256-bin histogram) in `dsp/heatmap.py` instead of `np.percentile`; keeps blobs visible with lower cost.

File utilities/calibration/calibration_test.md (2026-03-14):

# Camera–array calibration test setup

Reference for the physical layout used when testing heatmap vs camera alignment. Values are also in [config.py](../../src/software/acoustic_imager/config.py) as `CALIBRATION_*` for use in code.

## Layout

- **Camera on left**, **audio board (mic array) on right**; **same heading** (parallel).
- Camera optical axis and array “forward” (0°) are parallel; offset between them is lateral only.

## Distance

- **5 inches** — distance from camera to mic array center (depth).
- Measured along the common heading (perpendicular to the camera sensor plane).

## Lateral offset

- **7 inches** — from **camera optical center** to **center of audio board** (array center), in the plane at that depth.
- **Sign convention:** Positive = array center is to the **right** of camera center when the camera is on the left. So in this setup the array is +7 in from camera center.

## Units

- All values in **inches** here and in config for the test setup.
- Conversion to meters or to **pixels** (for overlay alignment) will need camera FOV and sensor/resolution; not defined in this doc.

## Use

- For calibration tests and for future overlay code that maps heatmap angle space to camera pixels (so the blob for the array appears over the array in the image).

## Array geometry

- Mic positions are **measured** and produced by [array_geometry.py](array_geometry/array_geometry.py) (table, CSV, `x_coords` / `y_coords` in meters, payload order).
- The app uses these in [config.py](../../src/software/acoustic_imager/config.py) as **`x_coords_hw`** and **`y_coords_hw`** for **SRC:HW** and **LOOP** (MUSIC/heatmap).
- For full reference (payload order, table columns, MUSIC summary), see [array_geometry.md](array_geometry/array_geometry.md).

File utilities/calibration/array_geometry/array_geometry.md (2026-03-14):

# Array geometry reference

This document explains the output of `array_geometry.py`: the **table** (and CSV) and the **MUSIC summary**. Use it as a reference when calibrating the heatmap or feeding geometry into the beamformer.

---

## 1. What the table is showing

The table is in the **flipped array-center frame**: origin at the array center, with the 180° flip applied so “camera top-left” matches your physical setup.

### Column meanings

| Column | Meaning |
|---|---|
| **pay** | Payload index 0–15. Row index = payload index; matches firmware/SPI order (e.g. payload 0 = U3, payload 1 = U2, …). |
| **label** | Physical mic name from the board (U1, U2, U6, …, U19). |
| **x_mm, y_mm** | Mic position in the **flipped** array-center frame, in mm. Negative values because after the flip the mics are in the “negative” quadrant relative to the chosen axes. |
| **x_m, y_m** | Same position in **meters**. This is the form used by MUSIC (SI units). |
| **dist_to_camera_mm** | Straight-line distance (mm) from the **camera** to that mic: `sqrt(x_cam² + y_cam² + z_cam²)` from the original camera-frame measurement. |
| **dist_to_center_mm** | 2D distance (mm) from the **array center** to that mic in the array plane. |
| **azimuth_deg** | Azimuth angle of the mic in the flipped frame (see below). |
| **min_dist_mm** | The “Min Dist. (mm)” from your FreeCAD CSV (measured camera–mic distance). Lets you cross-check the script against the raw data. |

---

## 2. What “azimuth_deg” is

In the script it’s computed as:

```python
azimuth_deg = math.degrees(math.atan2(y_f, x_f))
```

So it’s the **angle in the XY plane** from the positive x-axis to the mic, in degrees:

- **0°** = +x  
- **90°** = +y  
- **±180°** = −x  
- **−90°** = −y  

Your values (about −138° to −160°) put all mics in the **third quadrant** (negative x, negative y) in the flipped frame, which matches the geometry.

It’s the same “angle from the array” that shows up when you think of a source at some azimuth: MUSIC and your heatmap work in angles, so having each mic’s azimuth in this table helps you sanity-check that the layout (and any angle convention) is consistent.

---

## 3. Why these columns matter

| What | Why it matters |
|---|---|
| **x_mm, y_mm, x_m, y_m** | Define the array geometry in one place. **x_m / y_m** are exactly what you feed into MUSIC. |
| **dist_to_camera_mm / dist_to_center_mm** | For calibration and sanity checks (relative distances, symmetry, alignment with the camera). |
| **azimuth_deg** | Links geometry to angle space (DOA, heatmap direction). |
| **pay + label** | Map payload index (0–15) to physical mic so firmware, config, and MUSIC all agree: `x_coords[i]` / `fft_data[i, :]` = mic at `PAYLOAD_TO_MIC[i]`. |
| **min_dist_mm** | Direct check against your FreeCAD measurements. |

The table is both a **geometry reference** and a **cross-check** for calibration and for feeding the right numbers into the pipeline.

---

## 4. What the MUSIC summary is showing

The MUSIC summary is the **exact input set** your beamformer expects.

### 4.1. x_coords (m) and y_coords (m)

- **What:** Two length-16 arrays of mic positions in **meters**, in **payload order** (index i = payload index i: 0=U3, 1=U2, 2=U1, 3=U4, 4=U8, 5=U6, 6=U9, 7=U7, 8=U18, 9=U16, 10=U19, 11=U17, 12=U13, 13=U12, 14=U11, 15=U14).
- **Where it’s used:** In `beamforming.music_spectrum()` (and related code) these are the `x_coords` and `y_coords` arguments. For each test angle θ, the code builds the steering vector using  
  `k * (x_coords * cos(θ) + y_coords * sin(θ))`  
  so the phase delay at each mic is determined by these coordinates and the wavenumber *k*.
- **Why it matters:** MUSIC’s direction-of-arrival (DOA) and your heatmap directions depend entirely on this geometry. If you paste these arrays into your config (or calibration module), the pipeline uses your **measured** array layout instead of a generic Fermat spiral, which is what you want for calibrating the heatmap to the real hardware.

### 4.2. pitch (m)

- **What:** Mean **radial spacing** between mics (in meters), computed from the same flipped positions (e.g. from sorted radii).
- **Why it matters:** Used by **ESPRIT** and similar methods that assume or exploit a characteristic spacing (e.g. for a ULA or for wavelength/spacing checks). Having it printed lets you compare with config and with theory.

### 4.3. Payload order line

- **What:** Explicit mapping of payload index to mic: `0=U3, 1=U2, 2=U1, 3=U4, … 15=U14` (see `PAYLOAD_TO_MIC` in the script).
- **Why it matters:** Ensures that `x_coords[i]` / `y_coords[i]` and `fft_data[i, :]` from SPI refer to the same physical mic. The script is the single reference for this mapping.

### 4.4. Other MUSIC-relevant metrics (sanity checks)

The script also prints these so you can cross-check and tune the pipeline:

| Metric | Meaning | Why it matters |
|---|---|---|
| **speed_sound (m/s)** | Speed of sound used in steering vector (`k = 2πf/c`). Matches `config.SPEED_SOUND` (343 m/s). | Must match between array_geometry and config so angles and wavelengths are consistent. |
| **aperture_radius (m)** | Max distance from array center to any mic. | Drives angular resolution (~λ/aperture). Compare with config’s design aperture if you had one. |
| **wavelength at 30 kHz (m)** | λ = c/f at a reference frequency (middle of bandpass). Also prints λ/2. | Steering vector uses wavenumber k = 2π/λ. Use λ/2 for spatial Nyquist checks. |
| **pairwise distances (m)** | Min, max, and mean distance between any two mics. | If **max pairwise distance > λ/2** at your operating frequency, you can get grating lobes (ambiguous angles). Use to sanity-check operating band. |

### 4.5. Payload index and FFT layout

- **Payload index:** The script hardcodes `PAYLOAD_TO_MIC` and (optionally) `PAYLOAD_ADC_PIN_MIC` so that payload index 0..15 maps to ADC/PIN and mic label. Table and CSV use `payload_index`; row index = payload index everywhere.
- **FFT packed layout:** Per-mic RFFT from the firmware is 512 floats: `fft_data[0]=Re(DC)`, `fft_data[1]=Re(Nyquist)`; for bins 1..255, `fft_data[2*i]=Re(bin i)`, `fft_data[2*i+1]=Im(bin i)`. The script defines `FFT_FRAME_SIZE`, `FFT_HALF`, `FFT_N_BINS` and documents this layout; `acoustic_imager.spi.spi_protocol.unpack_packed_rfft_to_complex` implements it.

---

## 5. Summary

- **Table:** Documents the full geometry and distances/angles for checking and calibration.
- **MUSIC summary:** Gives you the drop-in arrays (`x_coords`, `y_coords` in payload order), `pitch`, `speed_sound`, payload→mic mapping, plus aperture, wavelength (and λ/2), and pairwise distances for sanity checks and tuning.

Keep this file next to `array_geometry.py` and the generated CSV so you can quickly look up column meanings and how the numbers feed into the pipeline.

---

## 6. Updating config from array_geometry

When you have new measured coordinates (e.g. from FreeCAD), update the app so the heatmap pipeline uses them:

1. **Edit** `MICS_RAW` (and optionally `ARRAY_CENTER_TO_CAMERA_MM`) in [array_geometry.py](array_geometry.py) with the new camera-frame measurements.
2. **Run** the script to regenerate the CSV and print the MUSIC summary:
   ```bash
   python3 utilities/calibration/array_geometry/array_geometry.py
   ```
3. **Copy** the printed `x_coords` and `y_coords` (and `pitch`) from the MUSIC summary into [config.py](../../../src/software/acoustic_imager/config.py) as `x_coords_hw`, `y_coords_hw`, and `pitch_hw` (section 4, HW geometry).

The app uses these values for SRC:HW and LOOP (MUSIC/heatmap); keeping config in sync with array_geometry ensures correct phase relationships in the pipeline.

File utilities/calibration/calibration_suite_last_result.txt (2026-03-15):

silence:True
pins:True
geometry:True
spi_devices:True
parsing_ok:True
metrics:True
post_gain:True

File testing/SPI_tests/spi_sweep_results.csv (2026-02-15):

spi_hz_req | sclk_hz_rep | elapsed_s | frames | fps | mb_s | mbps | bad_loopback | bad_parse | crc_checked | crc_skipped | bad_crc | cpu_pct_1core
30000000 | 30000000 | 5.008573513999863 | 410 | 81.85963505456719 | 2.6905624849735146 | 21.524499879788117 | 0 | 0 | 410 | 0 | 0 | 12.384005111759988
40000000 | 40000000 | 5.0041015839999545 | 496 | 99.11869127235617 | 3.257833144739803 | 26.062665157918424 | 0 | 0 | 496 | 0 | 0 | 19.79016579452415
50000000 | 50000000 | 5.003751676000093 | 673 | 134.4990806054516 | 4.420715781339983 | 35.36572625071987 | 0 | 0 | 673 | 0 | 0 | 26.466701102534397
60000000 | 60000000 | 5.004001783999911 | 676 | 135.09187829658296 | 4.4401998558520885 | 35.52159884681671 | 0 | 0 | 676 | 0 | 0 | 26.14431521953317
70000000 | 70000000 | 5.001398455000071 | 676 | 135.16219635013871 | 4.442511069636359 | 35.54008855709087 | 0 | 0 | 676 | 0 | 0 | 26.128532084732313
80000000 | 80000000 | 5.004066904999945 | 677 | 135.28995771890212 | 4.446710330304875 | 35.573682642439 | 0 | 0 | 677 | 0 | 0 | 26.028129214231896
90000000 | 90000000 | 5.006792280000127 | 672 | 134.21767119924993 | 4.411466416976947 | 35.29173133581558 | 0 | 0 | 672 | 0 | 0 | 26.568987199923658
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

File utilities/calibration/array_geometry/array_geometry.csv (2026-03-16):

payload_index | mic_label | x_mm | y_mm | x_m | y_m | dist_to_camera_mm | dist_to_center_mm | azimuth_deg | min_dist_mm
0 | U3 | 13.3 | 7.08 | 0.013300000000000001 | 0.007079999999999999 | 38.51 | 15.07 | 28.03 | 38.5
1 | U2 | 23.8 | 24.28 | 0.0238 | 0.024279999999999996 | 21.81 | 34.0 | 45.57 | 33.02
2 | U1 | 1.9 | 8.38 | 0.0018999999999999985 | 0.008379999999999999 | 47.4 | 8.59 | 77.23 | 47.4
3 | U4 | 9.7 | 17.78 | 0.009700000000000002 | 0.01778 | 36.68 | 20.25 | 61.39 | 36.68
4 | U8 | -6.8 | 14.38 | -0.006799999999999997 | 0.014379999999999999 | 53.19 | 15.91 | 115.31 | 53.19
5 | U6 | -11.6 | 1.48 | -0.011600000000000001 | 0.001479999999999997 | 62.42 | 11.69 | 172.73 | 62.42
6 | U9 | -18.3 | 10.48 | -0.018299999999999997 | 0.010479999999999996 | 65.23 | 21.09 | 150.2 | 65.23
7 | U7 | -2.2 | 24.08 | -0.0022000000000000027 | 0.024079999999999997 | 46.74 | 24.18 | 95.22 | 46.73
8 | U18 | -16.8 | -8.12 | -0.016799999999999995 | -0.008120000000000004 | 71.63 | 18.66 | -154.2 | 71.63
9 | U16 | 7.9 | -9.62 | 0.007899999999999999 | -0.009620000000000005 | 53.59 | 12.45 | -50.61 | 53.59
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

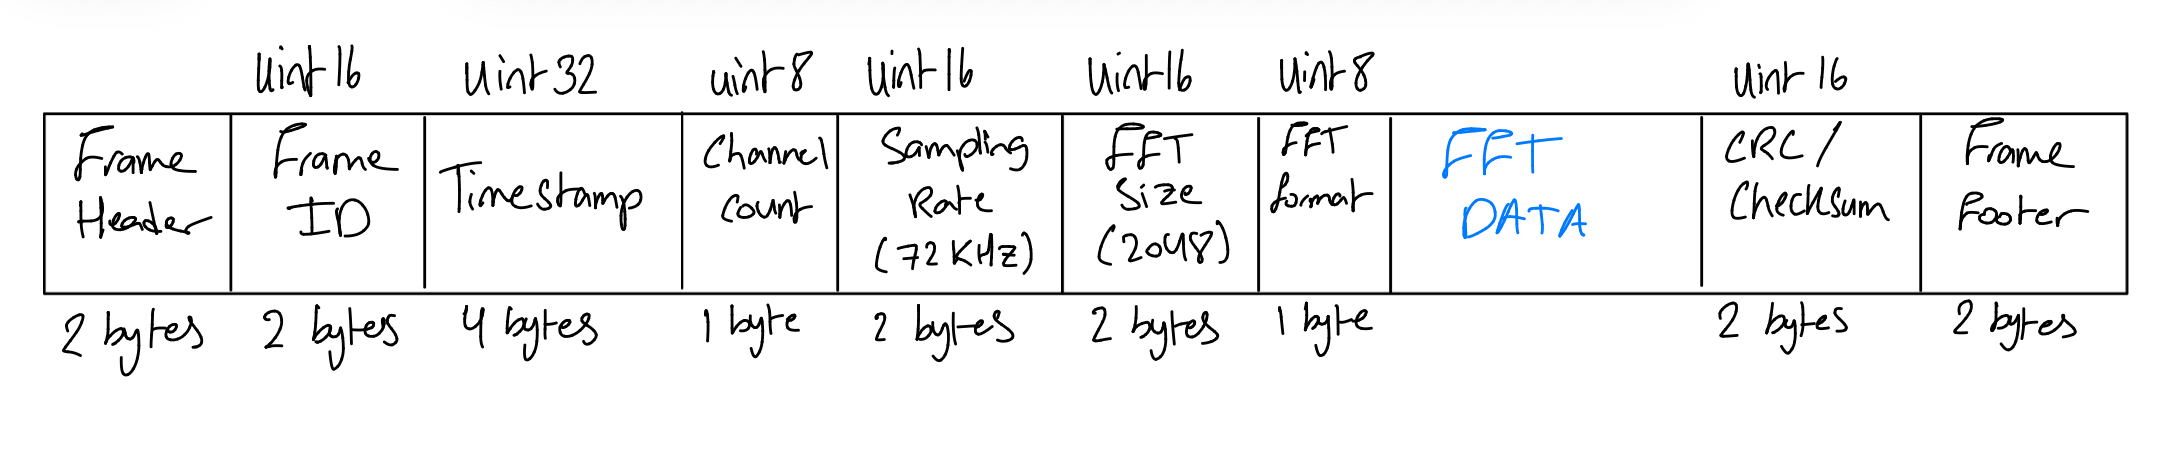
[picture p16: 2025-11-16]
testing/dataframe/dataframe_layout.jpeg

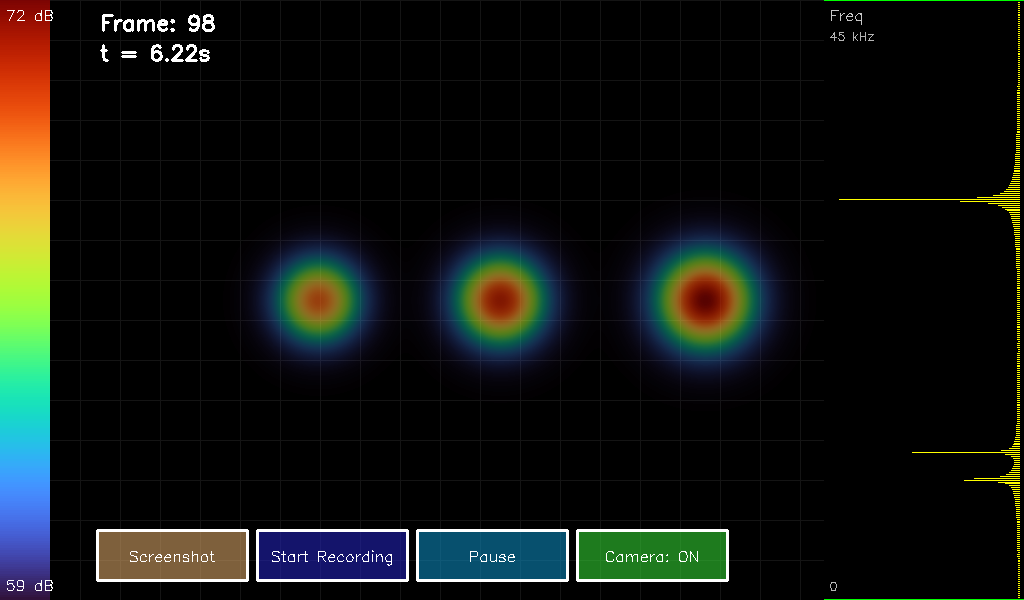
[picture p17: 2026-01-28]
testing/heatmap/heatmap_captures/screenshot_20260128_123143 2.png

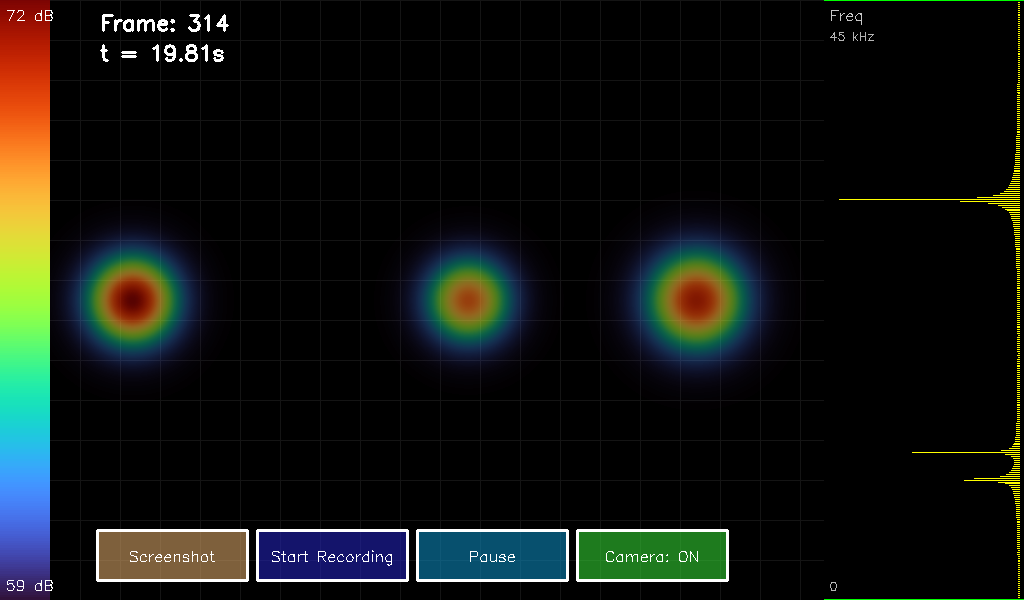
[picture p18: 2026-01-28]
testing/heatmap/heatmap_captures/screenshot_20260128_123157 2.png

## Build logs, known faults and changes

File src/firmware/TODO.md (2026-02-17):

# Embedded

This folder contains firmware and integration code for the STM32 microcontroller and Raspberry Pi.

---

### Raspberry Pi R&D & Setup
- **EF-01-01: Raspberry Pi Model Selection**  
  Compare Pi 4 vs Pi 5 for performance, power draw, and compatibility.  

- **EF-01-02: Camera Module Research**  
  Evaluate Pi Camera v2 vs v3 for latency, resolution, and ease of integration.  

- **EF-01-03: OS/GPU Acceleration Research**  
  Explore Raspberry Pi OS and GPU acceleration libraries (e.g., OpenCL).  

- **EF-02-01: OS Setup**  
  Install and configure Raspberry Pi OS Bookworm (64-bit headless).  

- **EF-02-02: Driver Installation**  
  Enable camera, GPIO, I²S/SPI/UART interfaces via `dtoverlay` configs.  

- **EF-02-03: Library Installation**  
  Install Python/C++ libraries for audio, video, and DSP (NumPy, OpenCV, ffmpeg).  

---

### STM32 Development
- **EF-03-01: Microphone Array Driver Setup**  
  Configure STM32 ADC/I²S to capture data from all 16 microphones.  

- **EF-03-02: DMA & Buffering**  
  Implement double-buffering with DMA to prevent sample loss.  

- **EF-03-03: Lightweight Preprocessing**  
  Apply offset removal and simple gain normalization before transmission.  

- **EF-04-01: Data Transmission (STM32 to Pi)**  
  Implement efficient packet transfer (I²S/SPI/UART).  
  Include headers or counters for error detection.  

---

### Raspberry Pi Integration
- **EF-04-02: Peripheral Integration**  
  Connect and configure LCD display, battery monitor, and other peripherals.  

- **EF-04-03: System Testing**  
  Measure CPU/GPU utilization during idle, acquisition, and DSP processing.

## STM32 Validation
### ADC Timing + Synchronization
- Are all ADCs triggered when you think they are?
- Is sampling rate correct?
-> We need to design a test where we can calculate the rate that the timer is firing and cross-reference with our settings to ensure that what we are observing matches what we expected
- Are the 4 ADCs aligned frame-to-frame?

#### Tests
- Only enable one ADC?

### DMA correctness
- Half/full callbacks fire at the expected rate
- Buffer layout matches your assumptions (interleaving order!)

### De-interleaving correctness
- Channel ch is really the mic you think it is

### FFT correctness
- Bin frequencies match expected
- Magnitudes / phases behave as expected

### SPI framing correctness
- Packet sizes, header, counter, checksum
- No drops, no misalignment, no endian surprises

### Others
- [ ] Test the USART2 and USB
- [ ] Test that ADC buffers are filling after adc_ready_mask change

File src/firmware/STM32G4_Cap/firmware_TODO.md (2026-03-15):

# Firmware TODO
**Priority 0**
- [/] Do the check the CLKCNT thing to see how many CCs it takes for FFT
   -> Yep — you’re thinking of the ARM DWT cycle counter, usually accessed through DWT->CYCCNT.

- [ ] (Optional/If beamforming is shit) Calculate and apply per channel phase compensation for mic sampling offset. Can in theory get the exact T(us) between mic samples and apply the phase shift so that each 4 mics per ADC don't have a phase offset from sequential sampling.
**Priority 1**
- [ ] **APP unit testing**
- [ ] Test app_read_battery_millivolts(void) (when we have battery)
- [ ] Investigate bug where sample_rate_hz is getting reset during app_loop()

- [ ] Talk to Rob about the whole audio passthrough (WDYM?)

**Priority 2**
- [ ] Code base clean-up
- [/] DSP unit testing (core done, could add some functions)
- [ ] Verify adc_scaler in dsp_pipeline.c that it should still be 3.3/4096

- [ ] Play with Gain Compensation setting in ADCs in CubeMX to see what it does. Research what we actually require for the beamforming to work
- [ ] Remember: ADC per-channel sampling time is 12.5 CCs, might want to set to 2.5 CCs for release.

- [ ] (QoL) Set up DSP library so it doesn't get removed after CubeMX code generation

- [x] Implement mic IDs
- [x] Find the CubeMX settings to make sure VRef Buf is enabled when code generated -> Run change by Rob to make sure it is conceptually correct
- [x] Evaluate using CMSIS for FFTs and fixed point representation
        -> Added CMSIS DSP to build. Probably not worth to switch to fixed point.
- [x] Add buffer de-interleaving
- [x] Fix adc_ready
- [x] Clean up branches
- [x] Fix the per-channel sampling cycles, make sure all ADCs continuous mode disabled
- [x] Check with a higher timer freq that the ADCs are alive with continuous conversion mode disabled
- [x] Check one ADC with 3 diff resistor combinations (increasing resistance) and check -> CHECKED, MUST FIX GAIN, EITHER 0 OR 3.3V
- [x] Test counter in the main loop for the interrupts
- [x] Bench debug that all the ADCs are firing at the correct rate
- [x] Do some averaging on the data (some stats like peak-to-peak, to see what we get)
- [x] Discuss labeling FFT frames (with counters?)
- [x] Fix USB CDC freeze issue (change usb_printf to non-blocking)

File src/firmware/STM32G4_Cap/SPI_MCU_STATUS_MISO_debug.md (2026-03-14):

# When does MCU_STATUS and MISO toggle?

NSS toggling (Pi side) means the Pi is asserting chip select. If **MCU_STATUS** (frame-ready) and **MISO** (STM32 → Pi data) never toggle, the STM32 is not driving them. This doc summarizes when the firmware does that.

## Firmware flow

1. **ADC DMA** (all 4 ADCs) fills buffers and sets bits in `adc_ready_mask` on half/full complete (see `adc.c`).
2. **app_loop()** (app_main.c) only calls `app_process_synced_window()` when:
   - **All 4 ADCs** have reported (either half or full): `(adc_pending_mask & ADC_READY_HALF_MASK) == ADC_READY_HALF_MASK` or same for `ADC_READY_FULL_MASK`.
   - And `!fft_in_progress && !get_spi_dma_busy()`.
3. **app_process_synced_window()** builds one SPI frame (header + 16 mic FFT payloads), then calls **spi_stream_tx_dma()**.
4. **spi_stream_tx_dma()** (spi_dma.c):
   - Arms `HAL_SPI_Transmit_DMA()` (STM32 will drive MISO when the Pi clocks).
   - Sets **MCU_STATUS (PE0) HIGH** so the Pi sees "frame ready".
5. When the **Pi** asserts NSS and clocks SCK, the STM32 (SPI slave) outputs the frame on **MISO**. When DMA completes, **HAL_SPI_TxCpltCallback** sets **MCU_STATUS LOW** and `spi_dma_busy = 0`.

So: **MCU_STATUS and MISO only toggle if the STM32 has reached step 4**, which requires the ADC path to have produced a synced window (all 4 ADCs ready).

## If MCU_STATUS never goes high

- **All 4 ADCs must be producing DMA half/full events.** If any ADC is not running, not triggered, or not connected, `adc_ready_mask` never has all four bits set, so `app_process_synced_window()` is never called and MCU_STATUS never goes high.
- Check: TIM6 running (triggers ADCs), all four `HAL_ADC_Start_DMA` called in `app_start()`, and ADC DMA callbacks firing (e.g. via USB `status` command or debug).

## If MCU_STATUS goes high once and never toggles (and MISO stays quiet)

- The first time all 4 ADCs are ready, the STM32 arms SPI TX DMA and sets MCU_STATUS high. If the **Pi never clocks** (NSS/SCK not reaching the STM32, or wrong pins), the slave transfer never completes.
- Then `spi_dma_busy` stays 1, so on the next synced window we **skip** `app_process_synced_window()` (because `!get_spi_dma_busy()` is false). So no new frame is sent, MCU_STATUS is never cleared by the callback (it stays high), and MISO never gets clocked out.
- **Fix:** Ensure NSS and SCK from the Pi reach the STM32 (J2 pin 6 = NSS, pin 5 = SCLK; STM32 PE3 = NSS, PE2 = SCK). If the Pi is toggling NSS but the STM32 NSS/SCK pins are not connected or are on the wrong header, the slave will never see the transaction.

## Wiring (STM32 → Pi)

| Signal | STM32 pin | Pi (SPI0) physical | Pi BCM |
|---|---|---|---|
| MCU_STATUS | PE0 | 26 | 7 |
| MISO | PE5 | 21 | 9 |
| NSS | PE3 | 24 | 8 |
| SCK | PE2 | 23 | 11 |

Confirm PE0 and PE5 are wired to Pi physical 26 and 21 (for SPI0).

## Quick checklist

1. **Firmware:** `main.c` has `#define MODE RELEASE` so the main loop runs `app_loop()` (not a test loop).
2. **ADCs:** All 4 ADCs started with DMA in `app_start()`; TIM6 started so conversions are triggered; ADC DMA callbacks run (e.g. USB `status` shows activity).
3. **Wiring:** NSS (PE3), SCK (PE2) from Pi to STM32 so the slave sees the transaction; MCU_STATUS (PE0) and MISO (PE5) from STM32 to Pi.
4. **One-shot stuck:** If MCU_STATUS went high once and never low, the first SPI transfer did not complete (Pi didn’t clock, or NSS/SCK not connected). Power-cycle or reset the STM32 after fixing wiring so `spi_dma_busy` clears.

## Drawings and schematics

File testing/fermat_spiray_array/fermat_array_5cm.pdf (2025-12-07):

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

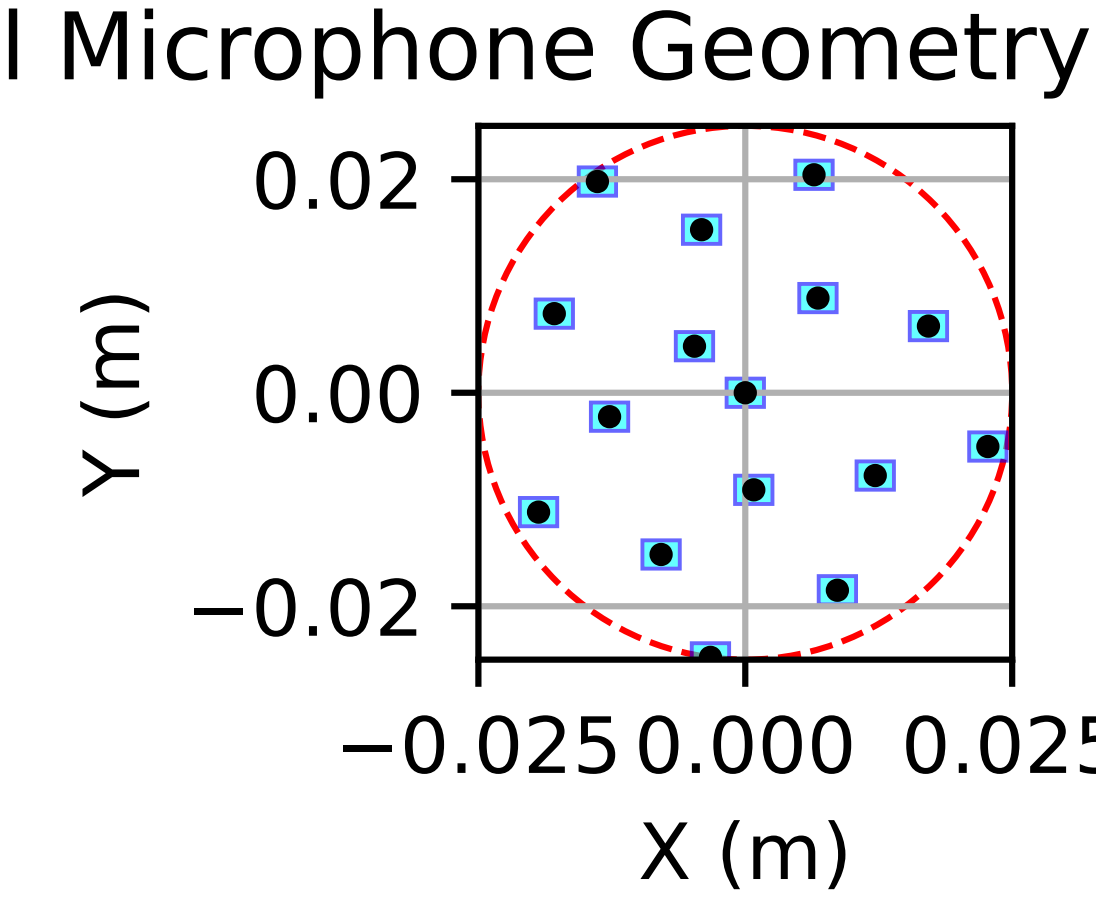
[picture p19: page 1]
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

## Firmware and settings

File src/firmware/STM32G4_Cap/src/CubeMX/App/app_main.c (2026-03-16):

/**
 * @file app_main.c
 * @brief Main application entry point for STM32G4 Acoustic Imager project
 * @details This file contains the main application logic and initialization
 */

/* =========================================================================
 * INCLUDES
 * ========================================================================= */
#include <stdlib.h>
#include <string.h>

#include "main.h"
#include "adc.h"
#include "dma.h"
#include "spi.h"
#include "tim.h"
#include "usart.h"
#include "usb_device.h"
#include "gpio.h"

#include "arm_math.h"

#include "app_main.h"

#include "protocol/spi_protocol.h"

#include "transport/spi_stream.h"
#include "transport/spi_stream_test.h"
#include "transport/spi_dma.h"

#include "dsp/dsp_pipeline.h"
#include "dsp/dsp_pipeline_test.h"

#include "usb/usb_debug.h"

#include "metrics/timing.h"



/* =========================================================================
 * DEFINES & CONSTANTS
 * ========================================================================= */
#define ADC_DMA_BUF_SIZE (2 * N_CH_PER_ADC * FRAME_SIZE) // 4096 samples per half-buffer
#define ADC_READY_HALF_MASK ((1u << N_ADCS) - 1u)
#define ADC_READY_FULL_MASK (ADC_READY_HALF_MASK << N_ADCS)
#define PASSTHROUGH_DISABLED_MIC 0xFFu
#define ADC_CLIP_LOW_THRESHOLD 200u
#define ADC_CLIP_HIGH_THRESHOLD 3900u

/* =========================================================================
 * STATIC VARIABLES
 * ========================================================================= */
// Each ADC gets dedicated DMA circular buffer (2 * 4 * 1024 = 8192 samples total)
// Half-buffer = 4096 samples (at 48kHz = 85.2ms)
static uint16_t adc1_buf[ADC_DMA_BUF_SIZE];
static uint16_t adc2_buf[ADC_DMA_BUF_SIZE];
static uint16_t adc3_buf[ADC_DMA_BUF_SIZE];
static uint16_t adc4_buf[ADC_DMA_BUF_SIZE];

static float mic_fft_buffer[FRAME_SIZE];
static float fft_avg[N_MICS][FRAME_SIZE];

// TODO: Test buffer for raw FFT output magnitude calcs, delete or pre-processor guard

static float mag_buffer[FRAME_SIZE/2 + 1];

static arm_rfft_fast_instance_f32 fft_instance;

static spi_stream_t spi_stream_ctx;

static uint32_t _print_counter = 0;
static uint32_t adc_pending_mask = 0;
static uint32_t clip_window_count = 0u;
static uint32_t clip_sample_count = 0u;
static uint16_t battery_millivolts_cached = 0u;

// TODO: sample_rate_hz bug
static uint32_t sample_rate_hz = 0;
#define SAMPLE_RATE_HZ 100000

static struct {
  uint8_t enabled;
  uint8_t mic_index;
} passthrough_state = {0u, PASSTHROUGH_DISABLED_MIC};

static char usb_cmd_buffer[APP_USB_CMD_MAX_LEN];
static uint32_t usb_cmd_length = 0u;

// Ping-pong processing flags
// Bit assignment: [4-7]=Full flags (ADC1-4), [0-3]=Half flags (ADC1-4)
volatile uint32_t adc_ready_mask = 0;
volatile uint8_t fft_in_progress = 0;  // Prevent overlapping FFT calculations

// Track which half of buffer is ready for FFT
// ready_half: 0=first half (0-1023), 1=second half (1024-2047)
volatile uint8_t ready_half[4] = {0};  // One per ADC

// Interrupt counters (for debug / watch)
volatile uint32_t irq_events = 0;            // total ADC IRQ events
volatile uint32_t irq_count_adc[4] = {0};    // per-ADC IRQ counters

/* =========================================================================
 * FORWARD DECLARATIONS
 * ========================================================================= */

/* static void module_init(void); */
/* static void module_process(void); */
static uint32_t app_get_tim6_trigger_hz(void);
static void app_process_synced_window(uint32_t half_offset, uint16_t frame_flags);
static const uint16_t *app_get_adc_buffer(uint8_t adc_index);
static uint16_t app_read_battery_millivolts(void);
static uint16_t app_get_cached_battery_mv(void);
static uint16_t app_scan_time_domain_clipping(uint32_t half_offset);
static void app_send_passthrough_window(uint32_t half_offset, uint32_t sample_rate_hz);
static void app_handle_usb_command(const char *command);

/* =========================================================================
 * PUBLIC FUNCTIONS
 * ========================================================================= */

// TODO: Deprecated
typedef struct {
    uint8_t header;
    uint8_t adc_id;
    uint32_t frame_counter;
    float fft_data[512]; // TODO: Correct MACRO use
    uint16_t checksum;
} __attribute__((packed)) SPI_Packet_t;

void app_init(void) {
  // Initialize FFT instance (precompute twiddle factors, etc.)
  arm_rfft_fast_init_f32(&fft_instance, FRAME_SIZE);

  // Initialize FFT performance measurement
  init_fft_performance_measurement();
  
  spi_stream_init(&spi_stream_ctx);
}


void app_start(void) {

  // Any additional startup logic can go here
  HAL_Delay(1000);  // Wait for peripherals to stabilize

  // Default LOW gain; then follow Pi's AUTO_GAIN_CNTL (no command yet = pull-down = LOW)
  HAL_GPIO_WritePin(GAIN_CNTL_GPIO_Port, GAIN_CNTL_Pin, GPIO_PIN_RESET);
  GPIO_PinState auto_gain = HAL_GPIO_ReadPin(AUTO_GAIN_CNTL_GPIO_Port, AUTO_GAIN_CNTL_Pin);
  HAL_GPIO_WritePin(GAIN_CNTL_GPIO_Port, GAIN_CNTL_Pin, (auto_gain == GPIO_PIN_SET) ? GPIO_PIN_SET : GPIO_PIN_RESET);

  // Calibrate all ADCs before use
  HAL_ADCEx_Calibration_Start(&hadc1, (uint32_t)ADC_SINGLE_ENDED);
  HAL_ADCEx_Calibration_Start(&hadc2, (uint32_t)ADC_SINGLE_ENDED);
  HAL_ADCEx_Calibration_Start(&hadc3, (uint32_t)ADC_SINGLE_ENDED);
  HAL_ADCEx_Calibration_Start(&hadc4, (uint32_t)ADC_SINGLE_ENDED);
  HAL_ADCEx_Calibration_Start(&hadc5, (uint32_t)ADC_SINGLE_ENDED);


  // Start Timer6 (triggers all ADCs synchronously)
  HAL_TIM_Base_Start(&htim6);
  HAL_Delay(1000);

  sample_rate_hz = app_get_tim6_trigger_hz();
  // Start all 4 ADCs with DMA (2048 samples = 1024×2 ping-pong)
  HAL_ADC_Start_DMA(&hadc1, (uint32_t*)adc1_buf, (uint32_t)(ADC_DMA_BUF_SIZE));
  HAL_ADC_Start_DMA(&hadc2, (uint32_t*)adc2_buf, (uint32_t)(ADC_DMA_BUF_SIZE));
  HAL_ADC_Start_DMA(&hadc3, (uint32_t*)adc3_buf, (uint32_t)(ADC_DMA_BUF_SIZE));
  HAL_ADC_Start_DMA(&hadc4, (uint32_t*)adc4_buf, (uint32_t)(ADC_DMA_BUF_SIZE));

  usb_dbg_init(16, 200);  // avg over 16 prints, print every 200 ms

}

/**
 * @brief Main application loop
 * @return void
 */
void app_loop(void) {
  // Poll Pi gain control: read AUTO_GAIN_CNTL and set GAIN_CNTL to match (HIGH/LOW gain)
  GPIO_PinState auto_gain = HAL_GPIO_ReadPin(AUTO_GAIN_CNTL_GPIO_Port, AUTO_GAIN_CNTL_Pin);
  HAL_GPIO_WritePin(GAIN_CNTL_GPIO_Port, GAIN_CNTL_Pin, (auto_gain == GPIO_PIN_SET) ? GPIO_PIN_SET : GPIO_PIN_RESET);

  // Main application loop - check for ADC data ready and process
#if MODE == DEBUG
  if (_print_counter++ >= 1000) {
    _print_counter = 0;
    usb_printf("Main loop heartbeat\r\n");

        
    // Report FFT performance
    usb_printf("FFT Avg Cycles: %d.%02d\r\n", PRINT_F2(get_fft_avg_cycles()));
    usb_printf("FFT Last Cycles: %d.%02d\r\n", PRINT_F2(get_fft_last_cycles()));
  }
#endif

  __disable_irq();
  adc_pending_mask |= adc_ready_mask;
  adc_ready_mask = 0;
  __enable_irq();

  if ((adc_pending_mask & ADC_READY_HALF_MASK) == ADC_READY_HALF_MASK) {
    adc_pending_mask &= ~ADC_READY_HALF_MASK;

    if (!fft_in_progress && !get_spi_dma_busy()) {
      app_process_synced_window(0u, SPI_FRAME_FLAG_SYNCED_ALL_MICS);
    }
    return;
  }

  if ((adc_pending_mask & ADC_READY_FULL_MASK) == ADC_READY_FULL_MASK) {
    adc_pending_mask &= ~ADC_READY_FULL_MASK;
    
    if (!fft_in_progress && !get_spi_dma_busy()) {
      app_process_synced_window(ADC_DMA_BUF_SIZE / 2u,
                                (uint16_t)(SPI_FRAME_FLAG_SYNCED_ALL_MICS |
                                           SPI_FRAME_FLAG_SECOND_HALF));
    }
    return;
  }
}


  /* Periodic debug print of IRQ counters over UART (every ~1000 iterations) */
  

void test_spi_stream_loop(void) {
  HAL_Delay(1000);
  // spi_stream_unit_test_build_packet();
  // spi_stream_unit_test_nulls();
  // spi_stream_unit_test_small_cap();
  // spi_stream_unit_test_frame_counter();
  // spi_loopback_unit_test();
  spi_loopback_unit_test2();
}

void test_dsp_pipeline_loop(void) {
  HAL_Delay(1000);
  dsp_unit_test_suite();
}

/* ============================================================================
 * STATIC FUNCTIONS
 * ============================================================================ */

/**
 * @brief Static helper function description
 * @return void
 */
static uint32_t app_get_tim6_trigger_hz(void)
{
  uint32_t timer_clock_hz = HAL_RCC_GetPCLK1Freq();

  if ((RCC->CFGR & RCC_CFGR_PPRE1) != RCC_HCLK_DIV1) {
    timer_clock_hz *= 2u;
  }

  return timer_clock_hz / ((htim6.Init.Prescaler + 1u) * (htim6.Init.Period + 1u));
}


static void app_process_synced_window(uint32_t half_offset, uint16_t frame_flags)
{
  // uint32_t sample_rate_hz;
  uint32_t batch_id;
  uint16_t battery_millivolts;
  uint8_t  mic_index;
  size_t   payload_len, final_len;

  uint16_t clipping_hits;

  fft_in_progress = 1u;

  // TODO: Might want to do this once only?
  // sample_rate_hz = app_get_tim6_trigger_hz();
  batch_id = spi_stream_next_batch(&spi_stream_ctx);

#if APP_BATTERY_READ_EVERY_N_FRAMES > 0u
  if ((batch_id % (uint32_t)APP_BATTERY_READ_EVERY_N_FRAMES) == 0u) {
    battery_millivolts_cached = app_read_battery_millivolts();
  }
  battery_millivolts = battery_millivolts_cached;
#else
  battery_millivolts = app_read_battery_millivolts();
#endif

#if APP_CLIP_DETECT_ENABLE
  clipping_hits = app_scan_time_domain_clipping(half_offset);

  if (clipping_hits > 0u) {
    frame_flags |= SPI_FRAME_FLAG_TIME_CLIPPING;
    clip_window_count++;
    clip_sample_count += clipping_hits;
  }
#else
  clipping_hits = 0u;
#endif

#if MODE != RELEASE && APP_CLIP_DETECT_ENABLE
  usb_printf("Clipping hits in window: %u, total clipped windows: %u, total clipped samples: %u\r\n",
             clipping_hits, clip_window_count, clip_sample_count);
#endif

#if MODE != RELEASE
usb_printf("Battery millivolts: %u mV\r\n", battery_millivolts);
usb_printf("Raw Battery millivolts: %u mV\r\n", (uint16_t)(battery_millivolts/BATT_DIVIDER_NUMERATOR));
#endif


  // Keep mic_index and set to 16 for now
  mic_index = N_MICS;
  payload_len = N_MICS * SPI_MIC_PAYLOAD_BYTES;
  final_len = 0;

  // Need to check here if SPI is done transmitting before starting next batch
  // Use pending flag with spi_dma_done flag?

  uint8_t *tx_buf = spi_dma_get_tx_buffer();
  size_t offset = 0;
  // Fill the header once

  offset += spi_stream_build_frame_header(&spi_stream_ctx,
                                          tx_buf,
                                          SPI_FRAME_PACKET_SIZE_BYTES,
                                          batch_id,
                                          mic_index,
                                          FRAME_SIZE,
                                          SAMPLE_RATE_HZ,
                                          (uint16_t)(frame_flags | SPI_FRAME_FLAG_PAYLOAD_COMPLEX | SPI_FRAME_FLAG_BATTERY_VALID),
                                          payload_len,
                                          battery_millivolts);

  if (offset == 0) {
    // Failed to build header, skip this batch
    fft_in_progress = 0u;
    return;
  }

  // Process all mics: FFT + bin average (no per-mic append)
  for (uint8_t adc = 0; adc < N_ADCS; adc++) {
    uint16_t *active_half = (uint16_t *)(app_get_adc_buffer(adc) + half_offset);

    for (uint8_t channel = 0; channel < N_CH_PER_ADC; channel++) {
      uint8_t mic_idx = adc * N_CH_PER_ADC + channel;
      process_adc_channel_pipeline(&fft_instance,
                                   active_half,
                                   channel,
                                   mic_fft_buffer);
      update_fft_bin_average(fft_avg[mic_idx], mic_fft_buffer, FRAME_SIZE, FFT_BIN_AVG_BETA);
    }
  }

  // One full bulk copy of entire payload (fft_avg is contiguous; size is fixed at build time)
  memcpy(tx_buf + offset, &fft_avg[0][0], SPI_FRAME_PAYLOAD_BYTES);
  offset += SPI_FRAME_PAYLOAD_BYTES;

  // Finalize (append checksum if enabled) and send
  final_len = spi_stream_finalize_frame(tx_buf,
                                        SPI_FRAME_PACKET_SIZE_BYTES - offset,
                                        offset);
  
  if (final_len == 0u) {
    fft_in_progress = 0u;
    return;
  }

  spi_stream_tx_dma(tx_buf, (uint32_t)final_len);

#if MODE != RELEASE
  usb_dbg_push_adc_window_4adc(&adc1_buf[half_offset],
                               &adc2_buf[half_offset],
                               &adc3_buf[half_offset],
                               &adc4_buf[half_offset],
                               FRAME_SIZE);

  if (passthrough_state.enabled) {
    app_send_passthrough_window(half_offset, sample_rate_hz);
  }
#endif

  fft_in_progress = 0u;
}

static const uint16_t *app_get_adc_buffer(uint8_t adc_index)
{
  switch (adc_index) {
    case 0u: return adc1_buf;
    case 1u: return adc2_buf;
    case 2u: return adc3_buf;
    default: return adc4_buf;
  }
}

static uint16_t app_read_battery_millivolts(void)
{
  uint16_t raw_counts = 0u;
  uint32_t sense_mv;

  if (ADC_ReadBatteryRaw(&raw_counts) != HAL_OK) {
    return 0u;
  }

  sense_mv = ((uint32_t)raw_counts * BATT_ADC_VREF_MV) / 4095u;
  sense_mv = (sense_mv * BATT_DIVIDER_NUMERATOR) / BATT_DIVIDER_DENOMINATOR;
  return (uint16_t)sense_mv;
}

static uint16_t app_get_cached_battery_mv(void)
{
  return battery_millivolts_cached;
}

static uint16_t app_scan_time_domain_clipping(uint32_t half_offset)
{
  uint32_t hits = 0u;

  for (uint8_t adc = 0u; adc < N_ADCS; adc++) {
    const uint16_t *active_half = app_get_adc_buffer(adc) + half_offset;

    for (uint32_t i = 0u; i < FRAME_SIZE; i++) {
      uint32_t base = i * N_CH_PER_ADC;
      for (uint8_t ch = 0u; ch < N_CH_PER_ADC; ch++) {
        uint16_t sample = active_half[base + ch];
        if (sample <= ADC_CLIP_LOW_THRESHOLD || sample >= ADC_CLIP_HIGH_THRESHOLD) {
          hits++;
        }
      }
    }
  }

  if (hits > 0xFFFFu) {
    return 0xFFFFu;
  }

  return (uint16_t)hits;
}

static void app_send_passthrough_window(uint32_t half_offset, uint32_t sample_rate_hz)
{
  uint8_t mic_index = passthrough_state.mic_index;
  uint8_t adc_index;
  uint8_t adc_channel;
  const uint16_t *adc_window;

  if (mic_index >= N_MICS) {
    return;
  }

  adc_index = mic_index / N_CH_PER_ADC;
  adc_channel = mic_index % N_CH_PER_ADC;
  adc_window = app_get_adc_buffer(adc_index) + half_offset;

  usb_dbg_stream_mic_window_csv(mic_index,
                                adc_window,
                                adc_channel,
                                FRAME_SIZE,
                                sample_rate_hz);
}

void app_usb_cdc_rx(const uint8_t *buf, uint32_t len)
{
  if (!buf) {
    return;
  }

  for (uint32_t i = 0; i < len; i++) {
    char ch = (char)buf[i];

    if (ch == '\r') {
      continue;
    }

    if (ch == '\n') {
      usb_cmd_buffer[usb_cmd_length] = '\0';
      app_handle_usb_command(usb_cmd_buffer);
      usb_cmd_length = 0u;
      continue;
    }

    if (usb_cmd_length + 1u < sizeof(usb_cmd_buffer)) {
      usb_cmd_buffer[usb_cmd_length++] = ch;
    } else {
      usb_cmd_length = 0u;
    }
  }
}

static void app_handle_usb_command(const char *command)
{
  unsigned long mic_index;

  if (!command || command[0] == '\0') {
    return;
  }

  if (strcmp(command, "help") == 0) {
    usb_printf("Commands: help, status, battery, clip, clip reset, pass off, pass <0-15>\r\n");
    return;
  }

  if (strcmp(command, "status") == 0) {
    usb_printf("status: pending=0x%02lX passthrough=%s mic=%u battery=%umV rate=%luHz clip_windows=%lu clip_hits=%lu\r\n",
               (unsigned long)adc_pending_mask,
               passthrough_state.enabled ? "on" : "off",
               (unsigned)passthrough_state.mic_index,
               (unsigned)app_get_cached_battery_mv(),
               (unsigned long)app_get_tim6_trigger_hz(),
               (unsigned long)clip_window_count,
               (unsigned long)clip_sample_count);
    return;
  }

  if (strcmp(command, "clip") == 0) {
    usb_printf("clip: windows=%lu hits=%lu thresholds=[<=%u, >=%u]\r\n",
               (unsigned long)clip_window_count,
               (unsigned long)clip_sample_count,
               (unsigned)ADC_CLIP_LOW_THRESHOLD,
               (unsigned)ADC_CLIP_HIGH_THRESHOLD);
    return;
  }

  if (strcmp(command, "clip reset") == 0) {
    clip_window_count = 0u;
    clip_sample_count = 0u;
    usb_printf("clip counters reset\r\n");
    return;
  }

  if (strcmp(command, "battery") == 0) {
    usb_printf("battery=%umV\r\n", (unsigned)app_get_cached_battery_mv());
    return;
  }

  if (strcmp(command, "pass off") == 0) {
    passthrough_state.enabled = 0u;
    passthrough_state.mic_index = PASSTHROUGH_DISABLED_MIC;
    usb_printf("passthrough disabled\r\n");
    return;
  }

  if (strncmp(command, "pass ", 5) == 0) {
    mic_index = strtoul(command + 5, NULL, 10);
    if (mic_index < N_MICS) {
      passthrough_state.enabled = 1u;
      passthrough_state.mic_index = (uint8_t)mic_index;
      usb_printf("passthrough mic=%u enabled\r\n", (unsigned)passthrough_state.mic_index);
    } else {
      usb_printf("invalid mic index, expected 0-%u\r\n", (unsigned)(N_MICS - 1u));
    }
    return;
  }

  usb_printf("unknown command: %s\r\n", command);
}

/* Old app_process_synced_window, can be deleted but leaving for now in case */

// static void app_process_synced_window(uint32_t half_offset, uint16_t frame_flags)
// {
//   // uint32_t sample_rate_hz;
//   uint32_t batch_id;
//   uint16_t battery_millivolts;

//   fft_in_progress = 1u;


//   // TODO: Might want to do this once only?
//   // sample_rate_hz = app_get_tim6_trigger_hz();
//   batch_id = spi_stream_next_batch(&spi_stream_ctx);
//   battery_millivolts = app_read_battery_millivolts();

//   for (uint8_t adc = 0; adc < N_ADCS; adc++) {
//     uint16_t *active_half = (uint16_t *)(app_get_adc_buffer(adc) + half_offset);

//     for (uint8_t channel = 0; channel < N_CH_PER_ADC; channel++) {
//       uint16_t mic_index = (uint16_t)(adc * N_CH_PER_ADC + channel);
//       size_t packet_len;
      
//       process_adc_channel_pipeline(&fft_instance,
//                                    active_half,
//                                    channel,
//                                    mic_fft_buffer);
      
//       // if (_print_counter++ == 100) {
//       // _print_counter = 0;

//       // for (int i = 0; i < FRAME_SIZE; i++) {
//       //   usb_printf("index=%d, value=%d.%02d\r\n",
//       //             i,
//       //             PRINT_F3(mic_fft_buffer[i]));          
//       // }
//       // rfft_packed_to_mag(mic_fft_buffer, mag_buffer, FRAME_SIZE);
//       // dsp_print_fft_report(SAMPLE_RATE_HZ, mag_buffer, FRAME_SIZE);
//       // }
     
      
//       uint8_t *tx_buf = spi_dma_get_tx_buffer();

//       packet_len = spi_stream_build_mic_packet(
//           &spi_stream_ctx,
//           tx_buf,
//           SPI_PACKET_SIZE,
//           batch_id,
//           mic_index,
//           mic_fft_buffer,
//           FRAME_SIZE,
//           sample_rate_hz,
//           (uint16_t)(frame_flags | SPI_FRAME_FLAG_PAYLOAD_COMPLEX | SPI_FRAME_FLAG_BATTERY_VALID),
//           battery_millivolts);

//       if (packet_len > 0u) {
//         // spi_stream_tx_blocking(spi_tx, packet_len);
//         spi_stream_tx_dma(tx_buf, packet_len);
//       }
//     }
//   }

//   usb_dbg_push_adc_window_4adc(&adc1_buf[half_offset],
//                                &adc2_buf[half_offset],
//                                &adc3_buf[half_offset],
//                                &adc4_buf[half_offset],
//                                FRAME_SIZE);

//   if (passthrough_state.enabled) {
//     app_send_passthrough_window(half_offset, sample_rate_hz);
//   }

//   fft_in_progress = 0u;
// }
  

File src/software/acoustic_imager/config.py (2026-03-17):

# config.py
"""
Central configuration/constants for the Acoustic Imager software.

Layout: core/UI/heatmap display first; then SIM (SRC: SIM + SRC: LOOP);
then Real hardware (SRC: HW) — SPI transport and heatmap pipeline.
Default source on startup is HW.
"""

from __future__ import annotations

import os
import struct
import numpy as np

# ===============================================================
# 1. Configuration
# ===============================================================
WINDOW_NAME = "Fermat Heatmap (SIM + SPI LOOPBACK) + Bandpass (MUSIC)"
N_MICS = 16
SAMPLES_PER_CHANNEL = 512

SAMPLE_RATE_HZ = 100000
SPEED_SOUND = 343.0
NOISE_POWER = 0.0005   # SIM source only (synthetic noise floor)

WIDTH = 1024
HEIGHT = 600
ALPHA = 0.7
# Single knob: menu button, dropdown items, top HUD pills, bottom HUD pills (0–1; higher = more opaque)
HUD_MENU_OPACITY = 0.92
BUTTON_ALPHA = HUD_MENU_OPACITY  # used by Button.draw for menu dropdown and back button
BUTTON_HITPAD_PX = 14

# Shared UI blue (BGR) for menu, HUD
MENU_ACTIVE_BLUE = (130, 82, 32)       # slightly darker blue
MENU_ACTIVE_BLUE_LIGHT = (165, 110, 48)  # gradient end

# Gallery Action surfaces style: "neon" (dark fill + neon edges) or "classic" (white on blue, pre-neon)
GALLERY_ACTION_STYLE = "classic"

# Single point of control for action button neon glow (0=off, ~0.32=default, 1=full)
ACTION_BTN_GLOW = 0.1

# Storage bar: one glow amount for all subelements (label, ring glow, % text, Used/Free); 0=off
STORAGE_BAR_GLOW = 0.28
STORAGE_BAR_BRIGHTNESS = 1.15
ACTION_BTN_BORDER_THICKNESS = 1

# Gallery action buttons: dark fill + neon edge (BGR) — used when GALLERY_ACTION_STYLE == "neon"
ACTION_BTN_FILL_DARK_TOP = (58, 58, 52)   # dark grey (slightly towards black)
ACTION_BTN_FILL_DARK_BOT = (32, 32, 28)   # darker grey
# Neon border color (electric blue) and glow strength (0=off, ~0.4=visible)
ACTION_BTN_NEON_BORDER_BGR = (255, 210, 100)  # BGR bright cyan-blue
ACTION_BTN_NEON_GLOW = 0.1                # border glow strength
ACTION_BTN_FILL_ALPHA = 1
ACTION_BTN_MODAL_FILL_ALPHA = 1
# Glassy shine on action buttons (0=off, ~0.11=subtle)
ACTION_BTN_SHINE_ALPHA = 0.05

# Classic style (when GALLERY_ACTION_STYLE == "classic"): white on blue, same as pre-neon
# Closed buttons (dock rows): darker blue gradient. Expanded (strip + panel after growth): lighter blue.
CLASSIC_ACTION_FILL_DARK_TOP = (90, 56, 22)   # BGR darker blue — closed dock rows
CLASSIC_ACTION_FILL_DARK_BOT = (115, 77, 34)   # darker blue bottom
CLASSIC_ACTION_FILL_TOP = (130, 82, 32)        # BGR lighter blue — expanded strip/panel (MENU_ACTIVE_BLUE)
CLASSIC_ACTION_FILL_BOT = (165, 110, 48)      # lighter blue bottom (MENU_ACTIVE_BLUE_LIGHT)
CLASSIC_ACTION_TEXT_BGR = (255, 255, 255)     # white text on blue
CLASSIC_ACTION_BORDER_BGR = (255, 255, 255)  # white border
CLASSIC_ACTION_GLOW = 0.06                 # very minor text/icon glow (0=off)

# Freq bar / bandpass: lighter neon blue so it stands out on dark bar
FREQ_BAR_BLUE = (230, 170, 80)
# Gallery filter/sort modal: goldish yellow for selected option (bandpass-style accent)
MODAL_ACTIVE_GOLD = (0, 200, 255)  # BGR goldish yellow

# Dock and content area gradients (BGR grey to black)
DOCK_GRADIENT_TOP = (55, 55, 55)
DOCK_GRADIENT_BOT = (20, 20, 20)
# Slightly darker for grid view and individual viewer background
BG_GRADIENT_TOP = (42, 42, 42)
BG_GRADIENT_BOT = (10, 10, 10)

FREQ_BAR_WIDTH = 150
DB_BAR_WIDTH = 80

# FPS defaults (MENU controls 30/60/MAX at runtime)
FPS_TARGET = 60
FPS_MODE_TO_TARGET = {"30": 30, "60": 60}

# Camera
CAMERA_INDEX = 0
CAMERA_WIDTH = WIDTH
CAMERA_HEIGHT = HEIGHT
USE_CAMERA = True
USE_LIBCAMERA = True

# Camera post-processing
CAMERA_BRIGHTNESS_ALPHA = 1.20   # contrast multiplier (1.0 = no change)
CAMERA_BRIGHTNESS_BETA  = 15      # brightness offset (-100 to +100 typical)
DETECTION_BOX_COLOR = (0, 215, 255)
#DETECTION_BOX_COLOR = (150, 180, 0) #teal
#DETECTION_BOX_COLOR = (0, 200, 200) # yellow

# Bandpass
F_DISPLAY_MAX = 45000.0
F_MIN_HZ_DEFAULT = 24000.0
F_MAX_HZ_DEFAULT = 35000.0

# Radar / position (branch-specific: state.py imports these)
RADAR_UI_DEFAULT = False
POSITION_SERVICES_DEFAULT = True
RADAR_MAP_TILE_STYLE_DEFAULT = "dark"   # "dark" | "light"
# RADAR_MAP_CACHE_DIR: set at runtime in main.py to repo_root / "data" / "map_tiles" (under main data folder)
DIRECTIONAL_HISTORY_RECORD_DEFAULT = False
RADAR_DEBUG_OVERLAY_DEFAULT = False
# Circular radar widget diameter (px)
RADAR_MAP_DIAMETER_PX = 200
# Tile URLs for radar map (use {z},{x},{y} in URL)
RADAR_MAP_TILE_URL_LIGHT = "https://tile.openstreetmap.org/{z}/{x}/{y}.png"
RADAR_MAP_TILE_URL_DARK = "https://a.basemaps.cartocdn.com/rastertiles/dark_all/{z}/{x}/{y}.png"
# Brightness multiplier for tiles (1.0 = unchanged). Dark tiles use higher value so they appear brighter than light.
RADAR_MAP_BRIGHTNESS_LIGHT = 1.0
RADAR_MAP_BRIGHTNESS_DARK = 3.25
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

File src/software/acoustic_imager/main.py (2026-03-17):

#!/usr/bin/env python3
"""
Acoustic Imager - Main Application

A real-time acoustic beamforming visualization system that supports:
- SIM (simulated) and SPI (hardware) data sources
- Interactive bandpass filtering
- MUSIC beamforming algorithm
- Camera background overlay
- Video recording and screenshots
- Configurable FPS and gain modes

This is the main entry point that orchestrates all modules.
"""

from __future__ import annotations

import logging
import sys
import time

log = logging.getLogger(__name__)
import json
from pathlib import Path
from typing import Optional

import numpy as np
import cv2
import os

# ===============================================================
# Display Configuration for SSH/Headless Operation
# ===============================================================
# Uncomment ONE of these if running over SSH:
# os.environ['DISPLAY'] = ':0'              # Use local display on Pi (monitor attached)
# os.environ['QT_QPA_PLATFORM'] = 'offscreen'  # Headless mode (no display, recording only)

# ===============================================================
# Import modularized components
# ===============================================================
from acoustic_imager import config
from acoustic_imager import state
from acoustic_imager.custom_types import LatestFrame, SourceStats

# Data sources
from acoustic_imager.sources.sim_source import SimSource
from acoustic_imager.sources.spi_source import SPISource
from acoustic_imager.sources.spi_loopback_source import SPILoopbackSource
from acoustic_imager.io.spi_manager import SPIManager
from acoustic_imager.io.gain_control import GAIN_CONTROL


# DSP modules
from acoustic_imager.dsp.beamforming import (
    directivity_ratio,
    music_spectrum,
    music_spectrum_2d,
    music_spectrum_2d_refined,
    music_2d_peak_angles,
)
from acoustic_imager.dsp.heatmap import (
    spectra_to_heatmap_absolute,
    spectra_to_blob_state,
    build_w_lut_u8,
    blend_heatmap_left,
    draw_crosshairs,
    find_local_max,
    percentile_uint8_fast,
    CROSSHAIR_TRACK_RADIUS,
    CROSSHAIR_DISMISS_RADIUS_PX,
)
from acoustic_imager.dsp.bars import (
    draw_db_colorbar,
    freq_to_y,
    y_to_freq,
)
from acoustic_imager.dsp.spectrum_analyzer import draw_spectrum_analyzer, spectrum_closest_curve_point

from acoustic_imager.system_info import get_system_network_info
from acoustic_imager.ui.top_hud import draw_hud, handle_hud_click
from acoustic_imager.ui.bottom_hud import draw_bottom_hud, BOTTOM_HUD_HEIGHT
from acoustic_imager.state import HUD

# I/O managers
from acoustic_imager.io.camera_manager import CameraManager
from acoustic_imager.io.gallery_metadata import load_metadata

# UI components (flat modules alongside hud and video_recorder)
from acoustic_imager.state import button_state
from acoustic_imager.ui.button import (
    buttons,
    menu_buttons,
    init_buttons,
    init_menu_buttons,
    update_button_states,
    draw_buttons,
    FPS_MODE_TO_TARGET,
)
from acoustic_imager.ui.screenshot import save_screenshot, draw_screenshot_flash
from acoustic_imager.ui.menu import draw_menu, get_recording_timestamp_rect, _MENU_DROPDOWN_KEYS
from acoustic_imager.ui.gallery import draw_gallery_view, get_gallery_items
from acoustic_imager.ui.handlers import (
    handle_button_click,
    handle_gallery_click,
    handle_gallery_mouse,
    handle_gallery_viewer_mouse,
    handle_email_modal_click,
)
from acoustic_imager.ui.wifi_modal import draw_wifi_modal, handle_wifi_modal_click, handle_wifi_modal_touch_drag
from acoustic_imager.io.magnetometer import MagnetometerReader, probe_i2c_magnetometer
from acoustic_imager.io.gps_reader import GPSReader
from acoustic_imager.io.position_manager import PositionManager
from acoustic_imager.io.directional_history_store import DirectionalHistoryStore
from acoustic_imager.ui.settings_modal import (
    draw_settings_modal,
    handle_settings_modal_click,
    handle_settings_modal_mouse,
    handle_settings_modal_scroll,
)
from acoustic_imager.ui.firmware_flash_modal import (
    draw_firmware_flash_modal,
    handle_firmware_flash_modal_click,
)
from acoustic_imager.ui.calibration_suite_modal import (
    draw_calibration_suite_modal,
    handle_calibration_suite_modal_click,
    handle_calibration_suite_modal_mouse,
    handle_calibration_suite_modal_scroll,
)
from acoustic_imager.ui.acoustic_radar_map import draw_radar_map_widget, update_detection_history
from acoustic_imager.ui.video_recorder import VideoRecorder
from acoustic_imager.ui.battery_icon import draw_battery_icon_for_view, battery_mv_to_percent

# region agent log
_AGENT_DEBUG_LOG_PATH = "/home/acousticlord/Capstone_490_Software/.cursor/debug-a9e491.log"
_AGENT_DEBUG_SESSION = "a9e491"


def _agent_debug_log(
    run_id: str,
    hypothesis_id: str,
    location: str,
    message: str,
    data: dict,
) -> None:
    try:
        payload = {
            "sessionId": _AGENT_DEBUG_SESSION,
            "runId": run_id,
            "hypothesisId": hypothesis_id,
            "location": location,
            "message": message,
            "data": data,
            "timestamp": int(time.time() * 1000),
        }
        with open(_AGENT_DEBUG_LOG_PATH, "a", encoding="utf-8") as _f:
            _f.write(json.dumps(payload, separators=(",", ":")) + "\n")
    except Exception:
        pass
# endregion

# ===============================================================
# External dependencies (from parent directories)
# Optional - provide fallbacks if not available
# ===============================================================
try:
    sys.path.append(str(Path(__file__).resolve().parents[1] / "dataframe"))
    from fftframe import FFTFrame  # type: ignore
except ImportError:
    # Fallback: minimal FFTFrame stub
    class FFTFrame:
        def __init__(self):
            self.channel_count = 0
            self.sampling_rate = 0
            self.fft_size = 0
            self.frame_id = 0
            self.fft_data = None

try:
    from heatmap_pipeline_test import create_background_frame  # type: ignore
except ImportError:
    # Fallback: create simple gradient background
    def create_background_frame(width: int, height: int) -> np.ndarray:
        """Create a simple gradient background."""
        bg = np.zeros((height, width, 3), dtype=np.uint8)
        for y in range(height):
            val = int(20 + (y / height) * 30)
            bg[y, :] = (val, val, val)
        return bg

try:
    sys.path.append(str(Path(__file__).resolve().parents[3] / "utilities"))
    from stage_profiler import StageProfiler  # type: ignore
except ImportError:
    # Fallback: minimal profiler stub
    class StageProfiler:
        def __init__(self, keep=120):
            self.stages = {}

        def start_frame(self):
            pass

        def mark(self, stage: str):
            pass

        def end_frame(self):
            pass

        def ms(self, stage: str) -> float:
            return 0.0
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

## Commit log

2025-09-28 heatmap testing
    created a fake data generator (realistic heatmap data using NumPy arrays)
    creates heatmap overlay over a black background
    records using ffmpeg
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2025-10-27 Data Acquisition Layout
    Created a cmake for the STM32 folder
    Laid out the initial steps we need for the data collection/acquisition from the mems mics.
    Created guides for what needs to be done with CubeMX and the microphone setup.
    Skeleton of the data acquisition is done, same with the organization of the repo. Need to populate the rest (including main)
    [configuringSTM.txt]
2025-10-27 bug fixes
    fixed the sample rate
    fixed up the logic to actually do the buffering correctly
2025-11-05 documentation mixup
    [configuringSTM.txt]
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2025-11-16 Embedded: Removed H7, Regenerated code for G4, fft and preprocessing moved to testing folder
    [configuringSTM.txt]
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2025-11-23 Testing: Heatmap fermat spiral with multiple srcs, Close X button fixed
2025-11-23 Testing: new simulation for heatmap fermat spiral live plot with bandpass filter
2025-11-23 Testing: heat map live src bandpass filter bugfix for degrees ??
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2025-12-07 Heatmap: added varied aperture tests with 7 audio tests to justify final diameter of spiral
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2026-01-14 Replace STM32_G4 with STM32G4_Cap
    [G4.ioc, adc.c, main.c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]
2026-01-26 camera fix
2026-01-28 New UI Features
    Implemented functioning buttons for:
    screenshots
    start/stop recording
    pause recording
    toggle camera
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2026-02-06 Adc config DMA config with sampling amount
    Used buncha bit-masking for the ADC config, missing just the FFT processing to work around that now
    [G4.ioc, adc.c, main.c]
2026-02-09 Added the CMSIS-DSP, missing Lib folder
    [main.c]
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2026-02-13 Fixed the .elf bullshit error from created a USB middleware
    [G4.ioc]
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2026-02-14 Added single throughput SPI test with fftframe + multi-loop varied SPI clock tests with fftframe
    [spi_sweep_results.csv]
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2026-02-14 deloyment script + repo cleanup + added .wav to gitignore
    [spi_sweep_results.csv]
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2026-02-15 FPS unit testing SPI with heatmap + profiler + updated bash script + updated UI + 2 simulation modes
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2026-02-15 Fixed hanging conflicts in embedded files
    [adc.c, main.c, main.h]
2026-02-15 added the spi and sources py files also added types.py to sources
    types.py remained in sources because python has a standard file called types and this could cause issues in the future
2026-02-15 Still fixing merge artifacts
    [G4.ioc]
2026-02-15 patch: fixed the menu buttons, spi frequency bins not populating in slider
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2026-02-15 fixed the record feature: timer retracts when menu is clicked, stop shows up after clicking rec, and changed the heatmap_captures to the data folder
    [main.py]
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2026-02-15 Fixed compilation issues after merge
    [G4.ioc, adc.c, main.c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]
2026-02-16 Added buffer de-interleaving and fixed adc_ready_mask
    [main.c]
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2026-02-17 Fixed DMA adc interrupts
    [G4.ioc, adc.c, main.c]
2026-02-17 FIXED ADC VALUES WITH VREF
    [main.c]
2026-02-17 CONFIG CHANGED, SYS AND ADC CONTINUOUS DISABLED
    internal voltage ref to be made more accurate
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2026-02-18 Add back the DSP library for the nth time and USB print working
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2026-02-19 fixed SPI loopback to random noise instead of 4 synthetic signals
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2026-02-19 Fix SPI CubeMX config
    [G4.ioc]
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2026-02-22 Patch: camera hue fixed to normal, spi_loopback_source.py mod for optional SPI1 pin-mode, david's bashscript modified to use SPI1
    [config.py, main.py]
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2026-02-27 scrolling on the gallery fixed
    [main.py]
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2026-02-27 menu buttons made transparent to match the remaining UI / trying out an auto-full screen function
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2026-02-27 silly mistake on my end woops - fullscreen fix
    [main.py]
2026-02-27 full screen will now update config too so that the frames match in resolution
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2026-02-27 rec pause and play fix
    [main.py]
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2026-02-27 select button fix in gallery try 3
2026-02-27 Modal added for delete, icons added for buttons, menu button matches the rest in terms of transparency
2026-02-27 gallery button fixes
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2026-02-27 reverted all touch handler things
    [main.py]
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2026-03-02 Gallery: refactored storage bar, introduced search, filter and sort with functioning modals
2026-03-02 added tag buttons upon clicking select in the menu
    This makes the existing 3 buttons; search, sort, and filter disappear temporarily
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2026-03-03 Gallery: standardized action buttons, image meta data organized onto discrete lines, UI enhancements for docks
2026-03-03 Main UI/UX: main bottom hud created with shot, rec, gallery; swipeable & tappable behaviour; Gallery: modal growth animation for action buttons
2026-03-03 menu button swipe fix
    [main.py]
2026-03-04 another memory bar formatting thing + changing the color of progress bar for it to match the buttons
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2026-03-04 Gallery: top hud action buttons refactored to match side dock btns; glow UI introduced - reduced overall balance
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2026-03-05 Gallery: Edit tags panel finally fixed
    [config.py]
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2026-03-05 added the placeholder battery icon and battery display handling, fixed up the tags so that the keyboard matches the modal and also got rid of cancel and save, moved up the text in the gallery
    [main.py]
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2026-03-05 fixing overlap of hud components (battery and time)
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2026-03-05 PER MIC FRAME SYNC FOR SPI PACKETTING TO RASPI
    changed from per-adc to per-mic
2026-03-05 fixing Move To button logic for the media handling with the Archive panel
2026-03-06 Main Detector: Top Hud now with 4th pill for wi-fi + battery status
2026-03-06 SETTINGS/HUD/GALLERYUI: added email support via SMTP, z-index priority scheme fixed for modals, new keyboard standard introduced for all action buttons
    [email_config.py, main.py]
2026-03-07 Spectrum Analyzer: Normal vs Db scaled mode added with below db ref, switch added to main menu
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2026-03-07 battery PA8/ADC5, beginner mic passthrough, batch ID and mic index, RAM management
    started with fixing the way we processed each adc independently, no bueno since if say for example that if ADC1 finished before ADC3, FFT would be on the wrong window, the frame wouldn't show the same moment the 16 mics would be showing
    Added PA8 as ADC5 input 1, used ADC_ReadBatteryRaw(), did a lil conversion on it and alsed packed it into every SPI frame header as battery_mv.
    Vibe coded this part: since there was no way to view raw mic audio, added command line interface through the serial monitor with "help, status, battery, pass<0-15> and pass off.
    Focused on the RAM issue of 172KB, there was only one f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
    [G4.ioc, adc.c, app_main.c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]
2026-03-07 Spectrum analyzer: dB ruler flipped orientation, red dot drag for precise bandpass measurements
    [main.py]
2026-03-07 Added REF mode: skip MUSIC for uniform 0db heatmap(sanity/calibration check for peak baseline)
    [config.py, main.py]
2026-03-08 Modified SPI header and fixed affected functions.
    [app_main.c, app_main.h, spi_protocol.h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]
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2026-03-08 Added new row of buttons; blank, wifi, and settings. Made the infrastructure for the wifi modal
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2026-03-09 Fixed and added more dsp unit tests. Update firmware_TODO
    [app_main.c]
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2026-03-11 Created the firmware flash button & modal. Created utilities folder where firmware flashing things will live.
2026-03-11 Fix errors from previous commit, add GPIO READY signal and control logic for SPI
    [app_main.c, app_main.h, spi_dma.c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]
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2026-03-13 Splash screen resized and working
    [spi_hex_dump.txt]
2026-03-13 SPI: spi_interface_config.md added containing instructions for flipping SPI_INTERFACE flag and STM32 vs RASPI pinouts for both interfaces
    [array_geometry.csv, spi_hex_dump.txt]
2026-03-13 Heatmap: gaussian ys now uses per-blob value, no longer collapsed to same x-value
    [config.py, main.py]
2026-03-13 Utilities: array geometric data updated calibration tests, metrics_debug.py write config either high or low
2026-03-13 Hardware: merged into main, switchhole made, fixed countersink horizontal angle, side strap connectors removed
    [Acoustic_Imager_4.0-Cut_BACK.step, Acoustic_Imager_4.0-Cut_BACK.stl, Acoustic_Imager_4.0-Cut_FRONT.step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]
2026-03-13 Radar: dark tiles and brightness fixed, api key added to env var
    [config.py]
2026-03-14 created fully merged deploy script, spi fixes to get boards working
    [spi_hex_dump.txt]
2026-03-14 Add Calibration Suite under Advanced in System Settings
    - New 'Calibration Suite' button in System Settings > Advanced
    - Popup modal with Start Calibration and scrollable log
    - Runs: config/calibration_test validation, mic array geometry, SPI devices, SPI magic probe
    - Scrollable log (arrows, track click, mouse wheel)
    Made-with: Cursor
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2026-03-14 Updated measurements in calibration scrit
    [array_geometry.csv]
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2026-03-14 Added more tests to the calibration suite, pushing now to fetch updated geometry files
    [calibration_suite_cal_dump.txt]
2026-03-14 Updating gitignore
    [calibration_suite_cal_dump.txt]
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2026-03-15 Calibration: better noise floor, SPI_ANGLE_STAB lowered, Directivity lowered, TOP K Bins 3, 1D tracking
    [config.py, main.py]
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2026-03-15 Heat pipeline profiling and config tuning; MUSIC skip + frozen bins; reduce flicker
    [config.py, main.py]
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2026-03-15 Revert "Merge pull request #12 from B-S200502/FFT-Fabz"
    This reverts commit 6d85b4ca20762cddd30a8a6cb2627ca703030ba2, reversing
    changes made to 2d6df0fa375a220e71987c6ca6ad4d6cefaa08d1.
    [app_main.c, dsp_pipeline.c, spi_protocol.h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]
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2026-03-15 Revert "Merge pull request #13 from B-S200502/feature/calibration_suite"
    This reverts commit d04aa925470c32eb5e37afe6e332e48e236e7894, reversing
    changes made to 2638150c6199a66c913b702ff502ca18b1dcc89b.
    [calibration_standalone_app.py, config.py, main.py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]
2026-03-15 Merging main with restored calibration
    [calibration_suite_cal_dump.txt]
2026-03-15 manually moved over the calibration suite over to main
    [calibration_suite_cal_dump.txt]
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2026-03-15 Fix missing bracket
2026-03-15 heat_scale: subsample percentile (k=4), fuse level+stretch; percentile from level-scaled subsample for correct visibility
    [calibration_suite_cal_dump.txt]
2026-03-16 calibrated to the new geometry
    [array_geometry.csv, calibration_suite_cal_dump.txt]
2026-03-16 Hardware: housing 4 quarters, fan internal support, camera closer to pi
    [Acoustic_Imager_4.0-Cut_BACK.step, Acoustic_Imager_4.0-Cut_BACK.stl, Acoustic_Imager_4.0-Cut_FRONT.step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]
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2026-03-17 fixed the orientation of the audio board as well as added system temp
    [config.py, main.py]
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
